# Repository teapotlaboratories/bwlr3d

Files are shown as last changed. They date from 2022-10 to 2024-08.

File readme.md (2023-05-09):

# Teapot BWLR3D
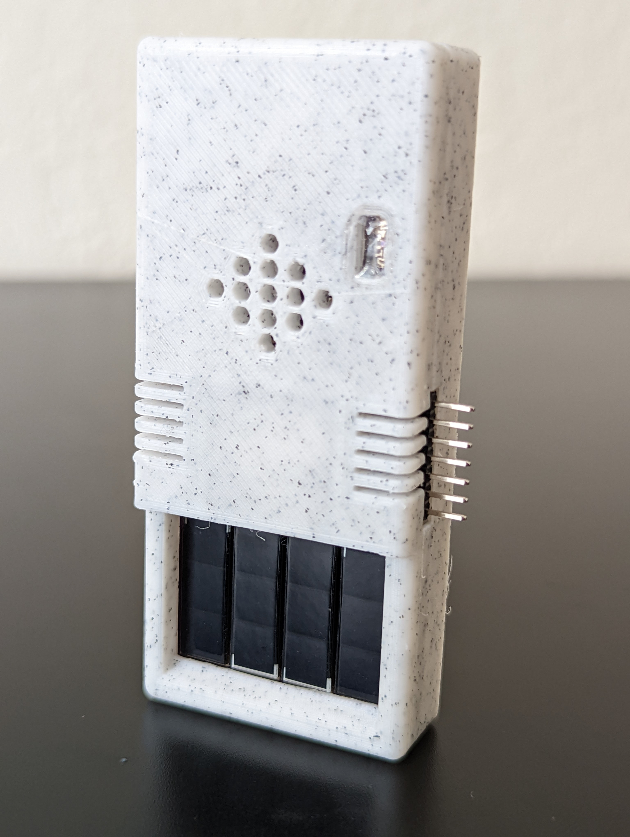
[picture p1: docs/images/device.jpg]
 
 
Teapot BWLR3D is an Asset Tracker and Environmental Sensor with Solar Energy Harvesting. 
The device is capable of sensing temperature, humidity, air pressure, air quality, light intensity using the on-board **BME688** plus **VEM7700**, and calculate device's AHRS using the **LSM6DSOX** as accelerometer and gyrometer with **LIS3MDL** as magnetometer. 
Equiped with low-power **L86-M33** GNSS module, the device is capable to locate itself anywhere in the world.
With **STM32WLE** MCU as it's core and **AEM10941** for solar charging, the device is capable ultra-low power operation with the possibility of indefinite battery-life by utilizing the solar charging capability.

Teapot BWLR3D is part of  [Teapot open-hardware project](https://github.com/teapotlaboratories). 
  
## Disclaimer
- The 1KM range is based on [AERQ - Air Quality Monitoring](https://github.com/Mircerson/AERQ/) design, but have not been tested on this device yet
- The position of the **BME688** sensor on the board might not be the most efficient
- The position of the **LIS3MDL** sensor might get interference from the surrounding components and the provided magnetic case does interfere with the sensor.

## Future Works
- Develop code to read sensor and send data when movement is detected. **LSM6DSOX** can be set to ultra-low power mode and set to wake MCU when movement is detected, all other sensors needs to be in power-down mode.
- Change `SW4` wiring from GND to 3V3, to allow booting to STM32WLE USART Bootloader. This enable the user to flash the RAK3172 module using STM32CubeProgrammer without ST-Link.

## Specification

- [RAK3172](https://docs.rakwireless.com/Product-Categories/WisDuo/RAK3172-Module/Overview/): An STM32WLE5CC module
- [AEM10941](https://e-peas.com/product/aem10941): Solar energy harvesting chip
- On-board sensors:
	- [L86-M33](https://www.quectel.com/product/gnss-l86): GNSS module
	- [LSM6DSOX](https://www.st.com/en/mems-and-sensors/lsm6dsox.html): Accelerometer and Gyrometer
	- [LIS3MDL](https://www.st.com/en/mems-and-sensors/lis3mdl.html): Magnetometer
	- [VEML7700](https://www.vishay.com/docs/84286/veml7700.pdf): Ambient Light Intensity meter
	- [BME688](https://www.bosch-sensortec.com/products/environmental-sensors/gas-sensors/bme688): Environmental sensor
- 3.3V only power/pin. 
- 12uA Deep-Sleep
- Switchable TX Power. 14 dBm(50mA) or 22 dBm(140mA) ( on 915MHz frequency )
- Supports LoRaWAN 1.0.3
- 1KM+ Range
- UART2 breakout for **Arduino** progamming
- SWD breakout for **Mbed OS/STM32Cube** programming
- IPEX antenna connector 
- 3.7 Volts LiPo Battery

## Schematics

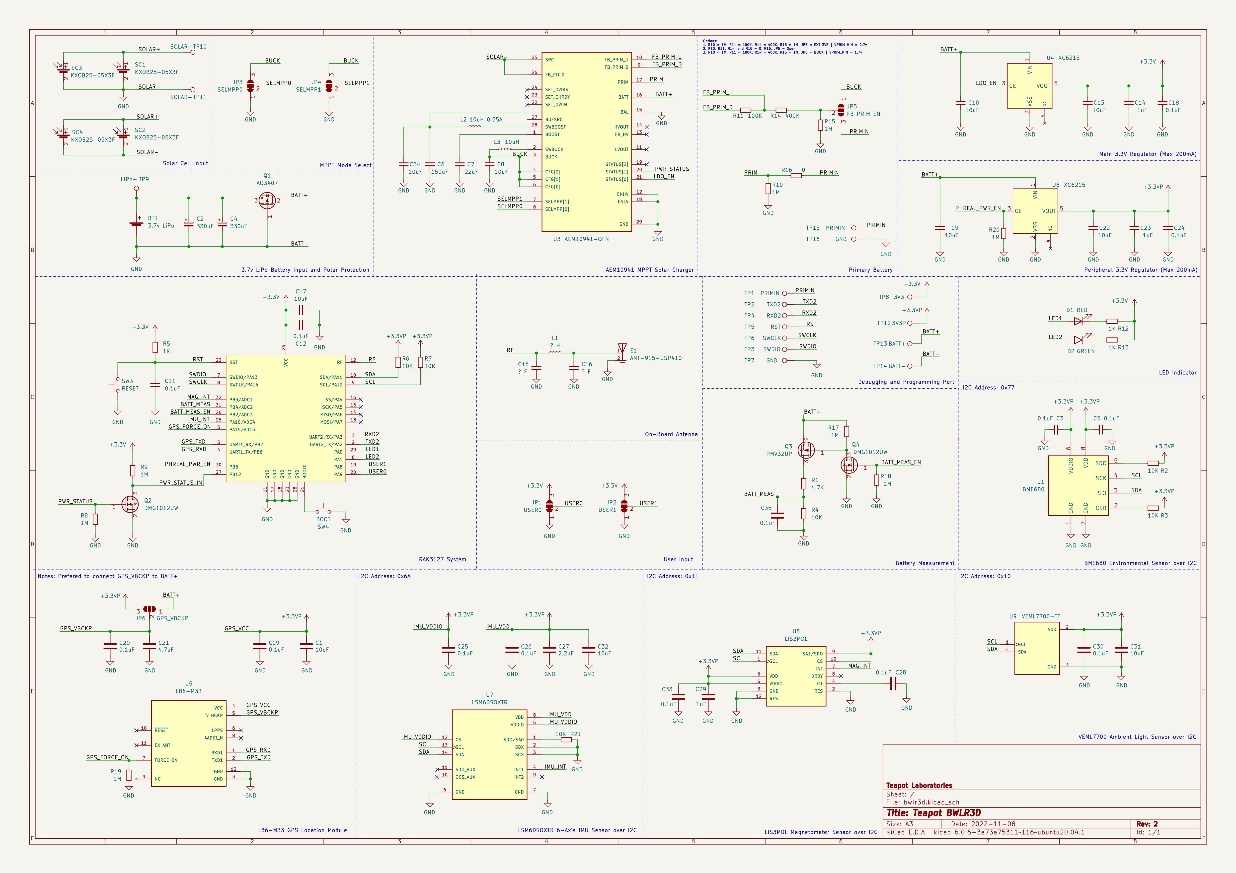
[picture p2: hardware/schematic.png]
schematic


Schematic revisions:
-   Revision 1: Initial design
-   Revision 2: Swap BATT_MEAS and IMU_INT pin, and add 0.1uF to voltage divider 

## Boards
 <p align="center">  pcb_render<br><b>PCB Render</b></p>

Built using KiCAD, the board is design to be as small as possible with all components placed on both side of the PCB.
The following design are based on the latest revision.
| Top Board | Bottom Board |
|--|--|
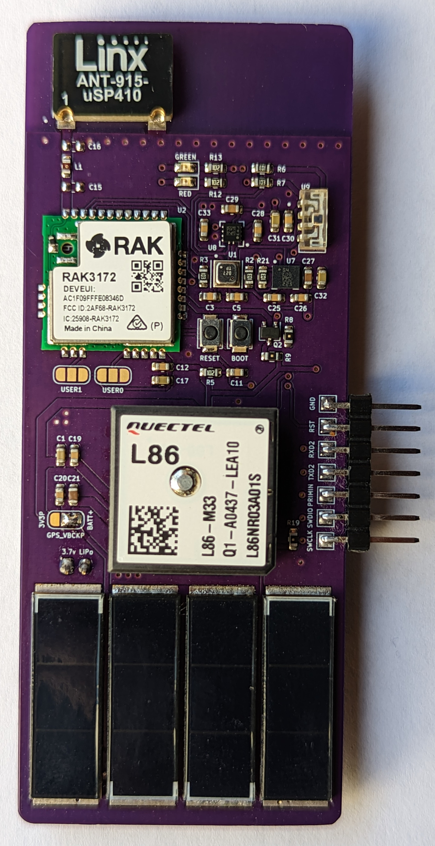
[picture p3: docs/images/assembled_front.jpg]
assembled_front
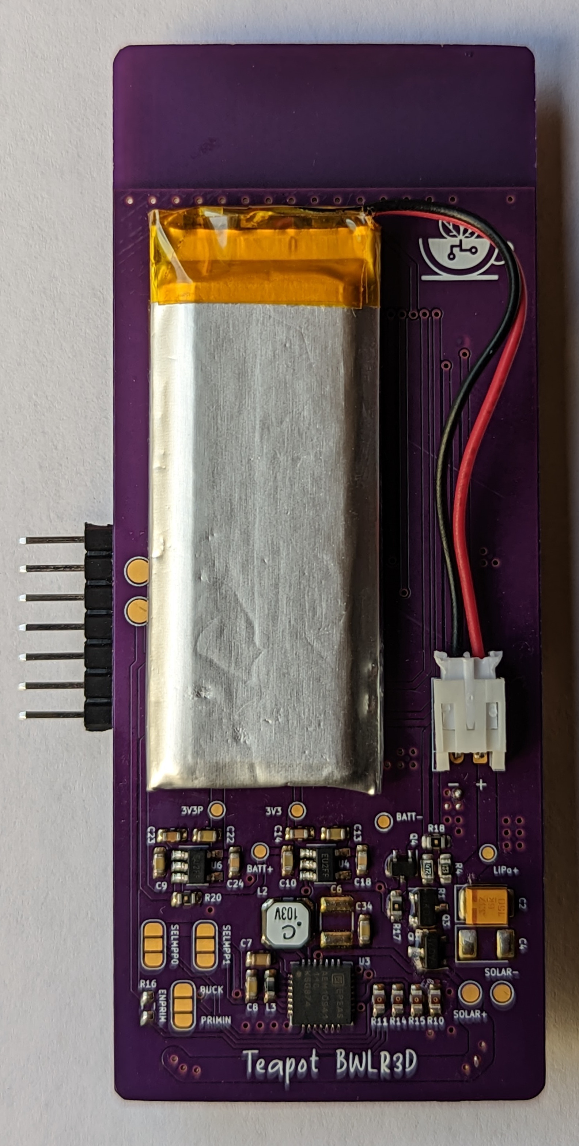
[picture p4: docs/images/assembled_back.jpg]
assembled_back
|  |  |
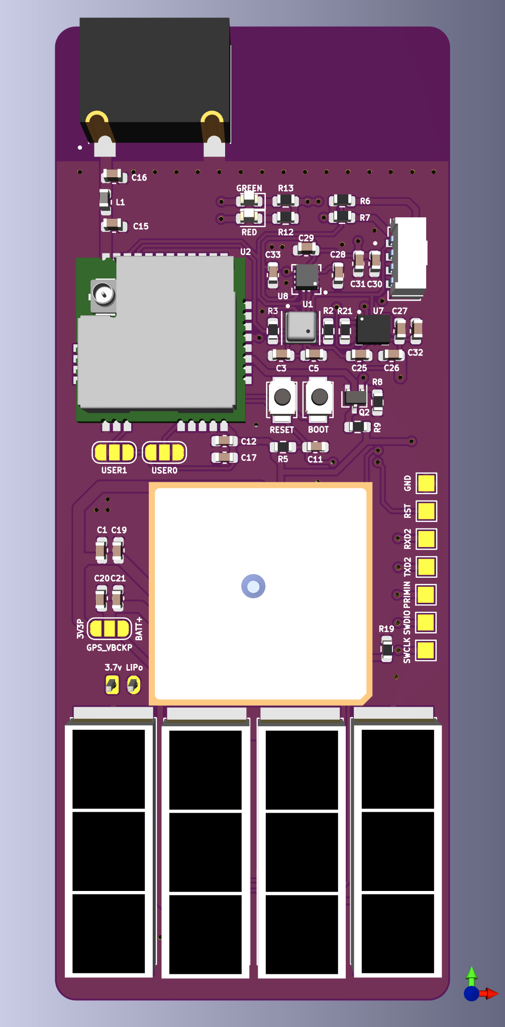
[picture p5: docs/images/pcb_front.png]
pcb_front
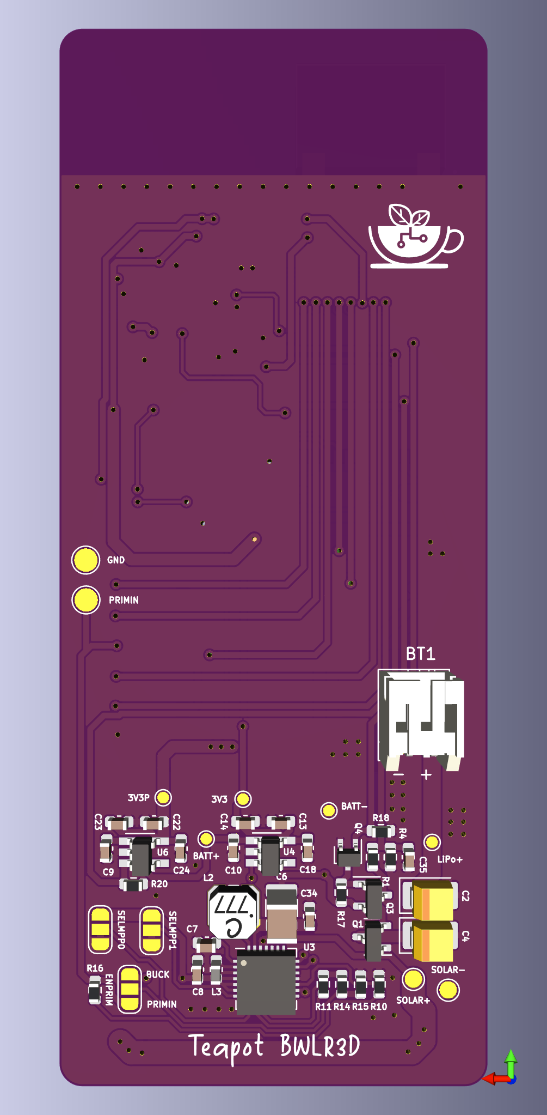
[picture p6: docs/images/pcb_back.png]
pcb_bottom
|  |  |

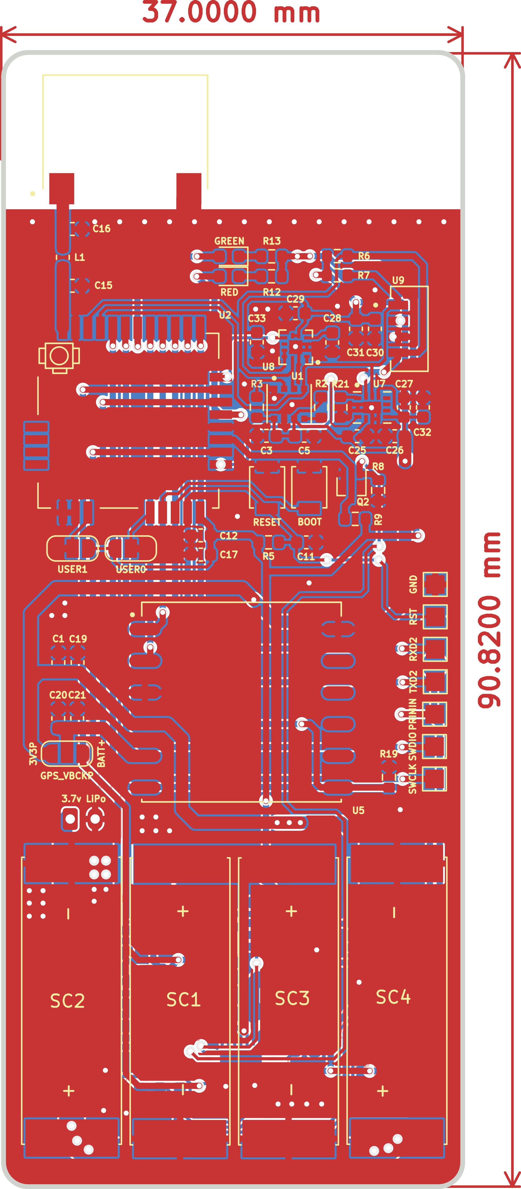
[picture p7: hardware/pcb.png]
pcb
 <p align="center"> <br><b>PCB Top and Bottom Layout</b></p> 
  
### Case
<p align="center">  case_render</p>

Built using [TinkerCAD](https://www.tinkercad.com), the cases are available with 2 variant, with or without the programming port. The cases are 3D printable with any generic 3D printer with/without suppport (depends on the orientation). The STL files are available [here](https://github.com/teapotlaboratories/bwlr3d/tree/main/hardware/case)
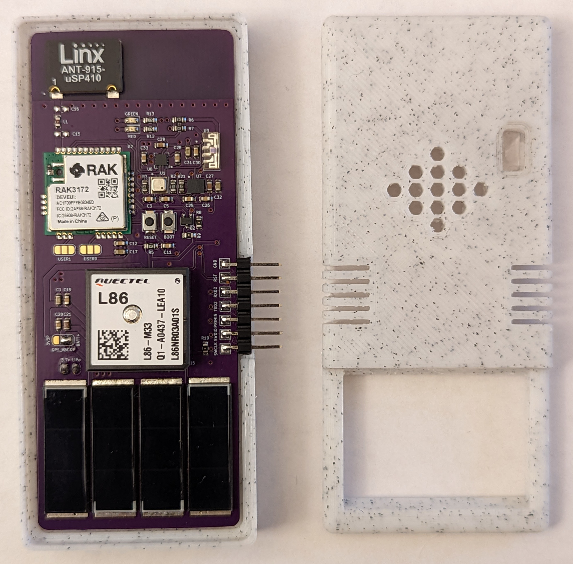
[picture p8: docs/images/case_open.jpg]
 <p align="center"><br><b>Case Open</b></p>

The case is design to be as small as possible with an additional magnets in the back to ease the placement of the sensor. The following are the list of material used at the time of testing:
- 3.7v LiPo Battery, 500 mAh 50mm x 22mm x 48mm
- 4 piece of 8mm x 2mm neodymium magnet

<p align="center">placement_showcase<br><b>Sensor Placement with Magnet</b></p>

### Measurement
Power consumption and solar charging current are measured using [Nordic PPK2](https://www.nordicsemi.com/Products/Development-hardware/Power-Profiler-Kit-2)  and [CurrentRanger](https://lowpowerlab.com/shop/product/152).
The following are the summary of the measurement:
- Transmit 102 bytes @ 14dBm:  225ms @ 48mA
- Deep-Sleep : 12 uA
- GNSS Fix - Cold Start: 15s @ 38mA
- GNSS Fix - Hot Start: 5s @ 35mA
- Sensor Read: 1.36s @ 9mA
- Direct Sunlight Solar Charge: 12mA
- Indirect Sunlight Solar Charge: 454uA

Notes: 
- GNSS time to fix depends on the conditions of the sky

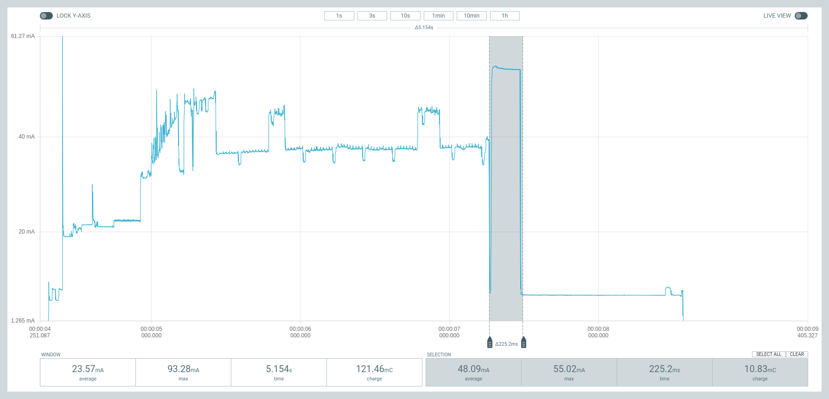
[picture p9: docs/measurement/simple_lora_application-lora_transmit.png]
lora_transmit
<p align="center"><br><b>LoRa Transmit</b></p>

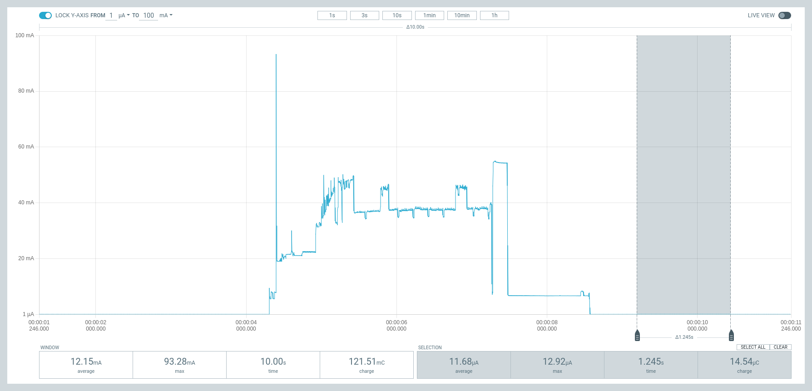
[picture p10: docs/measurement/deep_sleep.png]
deep_sleep
<p align="center"><br><b>Deep-Sleep</b></p>

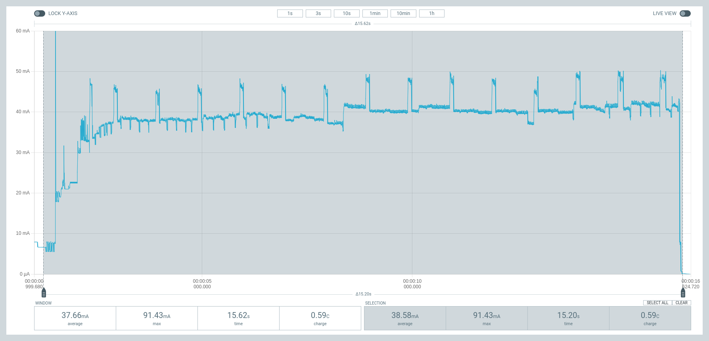
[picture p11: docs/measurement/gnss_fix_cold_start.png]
gnss_fix-cold_start
<p align="center"><br><b>GNSS Fix - Cold Start</b></p>

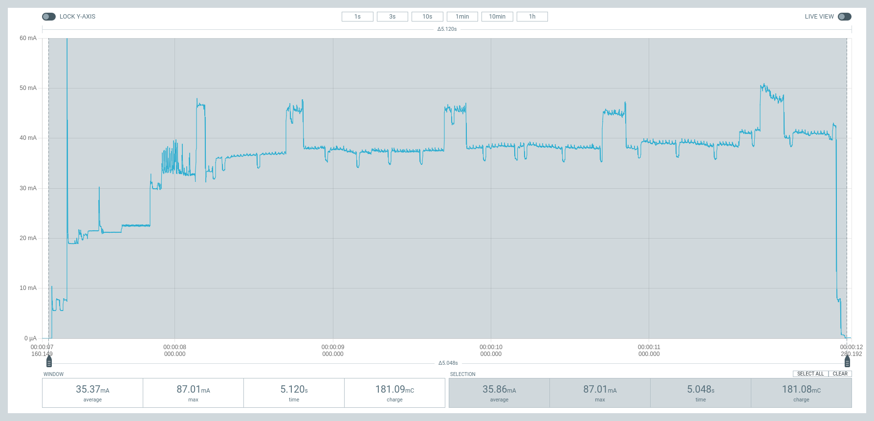
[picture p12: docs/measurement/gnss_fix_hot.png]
gnss_fix-hot_start
<p align="center"><br><b>GNSS Fix - Hot Start</b></p>

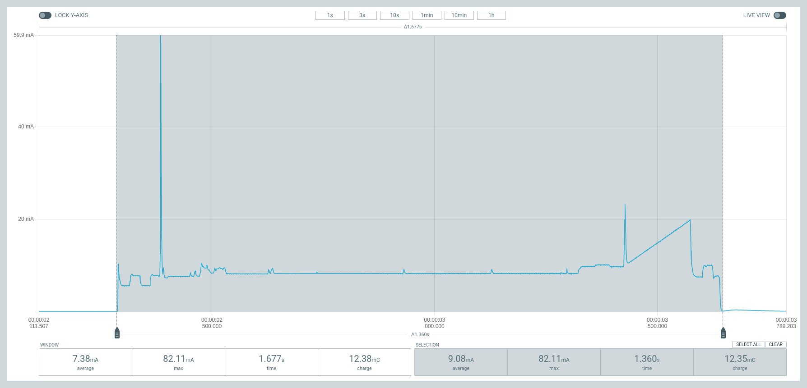
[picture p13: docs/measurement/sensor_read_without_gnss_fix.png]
sensor_read_without_gnss_fix
<p align="center"><br><b>Sensor Read</b></p>

| Solar Charge - Direct Sunlight | Solar Charge - Indirect Sunlight |
|--|--|
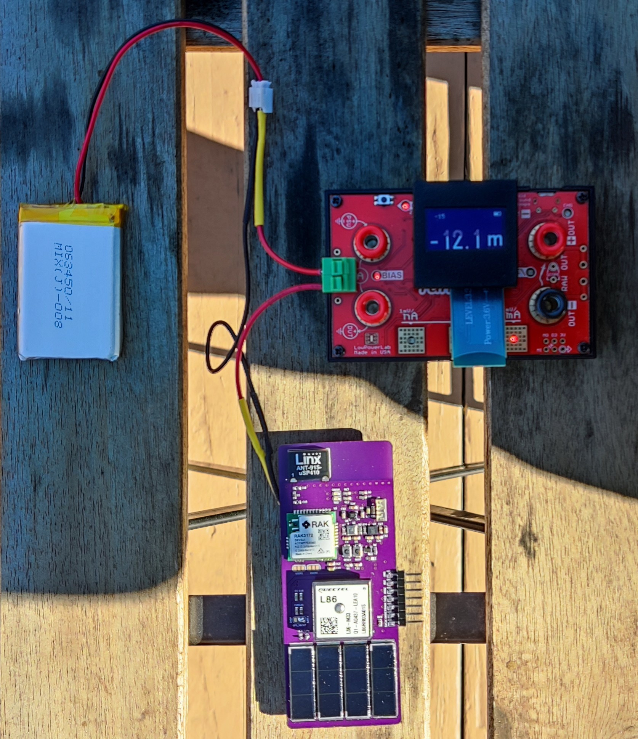
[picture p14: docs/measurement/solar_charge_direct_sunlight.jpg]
solar_charge_direct_sunlight
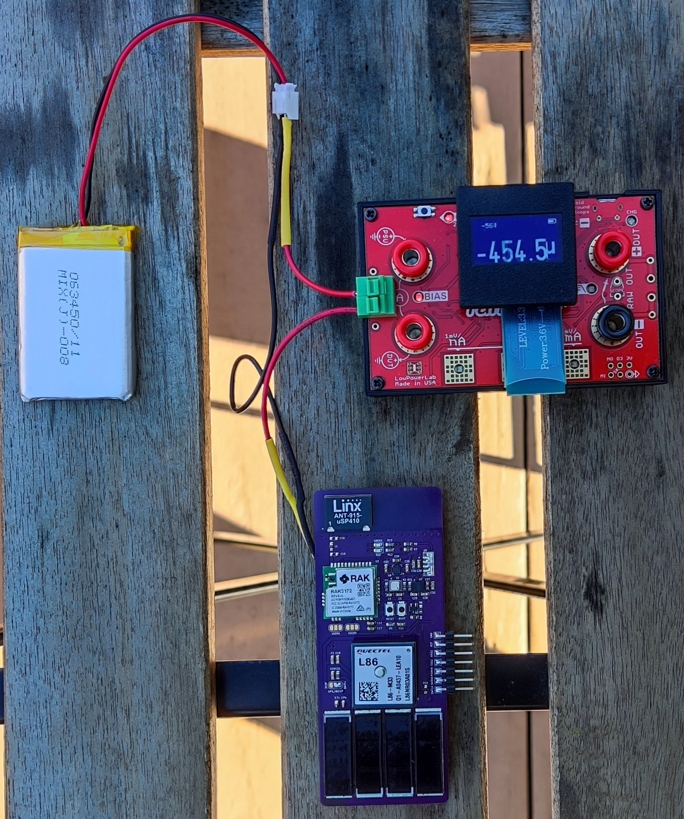
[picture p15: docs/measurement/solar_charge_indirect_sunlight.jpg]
solar_charge_indirect_sunlight
|  |  |

More measurement can be found [here](https://github.com/teapotlaboratories/bwlr3d/tree/main/docs/measurement)

### Bill Of Materials
Most of the components are generic and can be bought from any electornics/semi-conductor distributor. RAK3172 is the only component available in [RAKwireless store](https://store.rakwireless.com/products/wisduo-lpwan-module-rak3172?variant=40014759493830). The bill of materials can be downloaded [here](https://github.com/teapotlaboratories/bwlr3d/raw/main/hardware/bill_of_materials.csv)

> :warning: **Be sure to buy the RAK3172 variant without IPEX to use the On-Board Antenna** 

|Id |Designator |Package |Quantity|Designation |
|---|---|---|---|---|
|1  |BT1 |JST_PH_S2B-PH-K_1x02_P2.00mm_Horizontal|1 |3.7v |
|2  |C14,C23,C29 |C_0603_1608Metric |3 |1uF |
|3  |C17,C31,C32,C1,C9,C22,C8,C10,C34,C13 |C_0603_1608Metric |12 |10uF |
|4  |C2,C4 |CP_EIA-3528-15_AVX-H_Pad1.50x2.35mm |2 |330uF |
|5  |C21 |C_0603_1608Metric |1 |4.7uF |
|6  |C27 |C_0603_1608Metric |1 |2.2uF |
|7  |C5,C20,C26,C12,C28,C19,C30,C11,C25,C3,C33,C24,C18,C35|C_0603_1608Metric |14 |0.1uF |
|8  |C6 |C_1210_3225Metric |1 |150uF |
|9  |C7 |C_0603_1608Metric |1 |22uF |
|10 |D1 |LED_0603_1608Metric |1 |RED |
|11 |D2 |LED_0603_1608Metric |1 |GREEN |
|12 |E1 |ANT-915-USP410 |1 |ANT-915-USP410|
|13 |L2 |IND_LPS4012-103MRB |1 |10uH |
|14 |L3 |L_0603_1608Metric |1 |10uH |
|15 |Q1 |SOT-23 |1 |PJA3407 |
|16 |Q2,Q4 |SOT-323_SC-70 |2 |DMG1012UW |
|17 |Q3 |SOT-23 |1 |PMV27UPER |
|18 |R1 |R_0603_1608Metric |1 |4.7K |
|19 |R11 |R_0603_1608Metric |1 |100K |
|20 |R12,R13,R5 |R_0603_1608Metric |3 |1K |
|21 |R14 |R_0603_1608Metric |1 |400K |
|22 |R16 |R_0603_1608Metric |6 |0 |
|23 |R7,R2,R3,R6,R21,R4 |R_0603_1608Metric |6 |10K |
|24 |R9,R8,R19,R15,R18,R10,R17,R20 |R_0603_1608Metric |8 |1M |
|25 |SC4,SC1,SC3,SC2 |KXOB25-05X3F |4 |KXOB25-05X3F  |
|26 |SW3 |SW_SPST_B3U-1000P |1 |RESET |
|27 |SW4 |SW_SPST_B3U-1000P |1 |BOOT |
|28 |U1 |BME688 |1 |BME688 |
|29 |U2 |RAK3172 |1 |RAK3172 |
|30 |U3 |QFN-28-1EP_5x5mm_P0.5mm_EP3.35x3.35mm  |1 |AEM10941-QFN  |
|31 |U5 |L86-M33 |1 |L86-M33 |
|32 |U6,U4 |SOT-23-5 |2 |XC6215 |
|33 |U7 |PQFN50P250X300X97-14N_0.59x0.30 |1 |LSM6DSOXTR |
|34 |U8 |LGA12_ST |1 |LIS3MDL |
|35 |U9 |VEML7700-TT |1 |VEML7700-TT |

## Programming

> :warning: **Board can only be powered using the LiPo Battery** 

Programming the device can be done over the **UART2** or **SWD**, available on the right side of the board.
Out of the factory, the RAK3172 chip ships with an **AT firmware** that can be tested by connecting a USB-to-UART bridge to the **UART2** port.

The following are some very good tutorial to start developing with the device:

 - [Communicating with the AT firmware](https://docs.rakwireless.com/Product-Categories/WisDuo/RAK3172-Module/Quickstart/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)
 - [Programming with Arduino](https://docs.rakwireless.com/Product-Categories/WisDuo/RAK3172-Module/Quickstart/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)
 - [Programming with STM32Cube](https://docs.rakwireless.com/Product-Categories/WisDuo/RAK3172-Module/Low-Level-Development/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)
 - [Programming with MbedOS](https://github.com/hallard/LoRa-E5-Tiny/blob/main/README.md#compile-and-flash-firmware)

For connecting to the **UART2** port, use any USB-to-UART bridge module. In testing, the [Sparkfun](https://www.sparkfun.com/products/14050) board is used for communication with AT firmware and programming over **Arduino**.
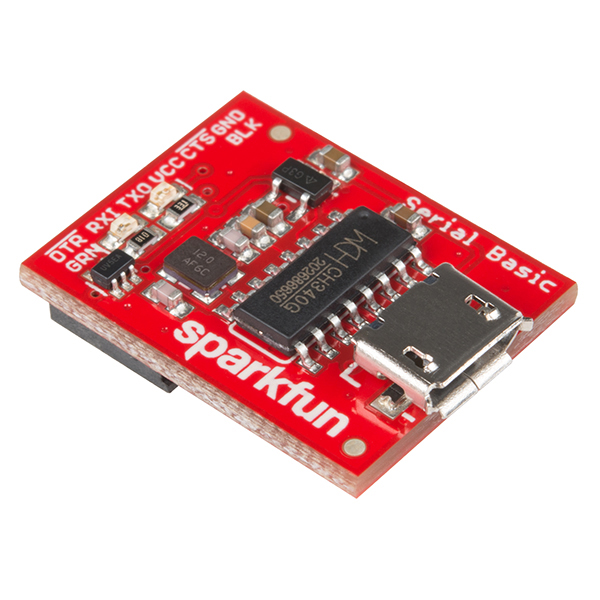
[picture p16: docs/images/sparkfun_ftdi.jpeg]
 <p align="center"> <br>Sparkfun USB-to-UART Bridge</p>

> :warning: **Be sure to only use 3.3V module. Do not 5V module** 

For connecting to the **SWD** port, use ST-Link v2  in-circuit debugger and programmer from STM. In testing, ST-Link v2 clone will not work. The ST-Link v2 should atleast be reconizeable by the [STM32CubeProgrammer](https://www.st.com/en/development-tools/stm32cubeprog.html).
A cheap and alternative way to get an authorized ST-Link is to buy a Nucleo board, cut the top part which contain the ST-Link and use it as an external programmer.
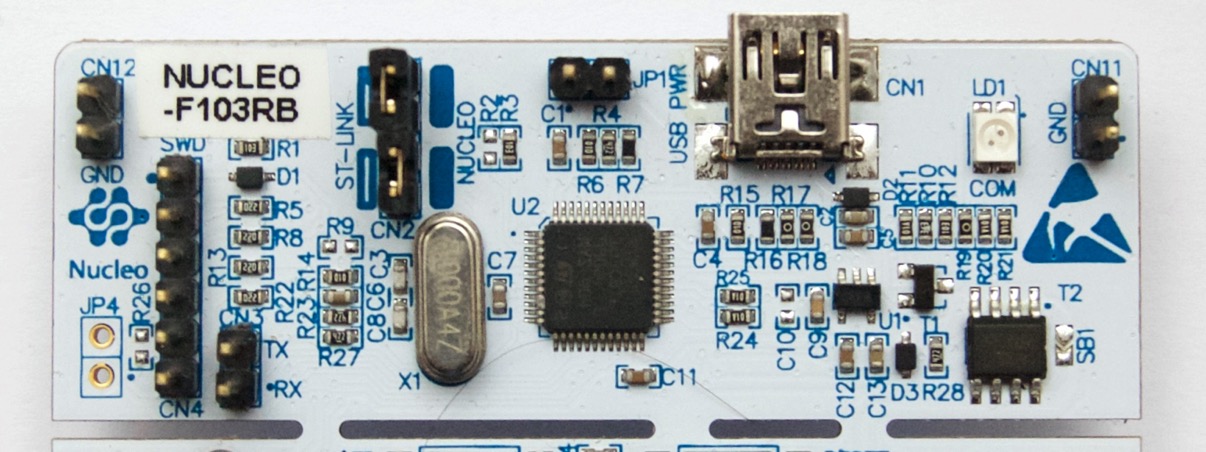
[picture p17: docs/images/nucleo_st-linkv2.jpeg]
 <p align="center"> <br>ST-Link v2 from a Nucleo Development Board</p>
Here are some good tutorial to convert a Nucleo to and external ST-Link v2:

 - https://www.radioshuttle.de/en/turtle-en/nucleo-st-link-interface-en/
 - https://jeelabs.org/book/1547a/index.html

## Notes
There are some issue, notes, and behavior that was discovered at the time of testing and development. The following are those discovery:
- Soldering the solar cell is better to be done manually using a soldering iron. Without proper reflow oven, it may damage the solar cell and reduces it's efficiency
- PRIMIN is available to use as the input for AEM10941 Primary Battery input. See schematic for more detail	

## Reference
The project won't be possible without the amazing work from people across the globe. The following are the reference to those awesome projects:

 - [LoRa e5 Tiny](https://github.com/hallard/LoRa-E5-Tiny)
 - [AERQ - Air Quality Monitoring](https://github.com/Mircerson/AERQ/)
 - [TSEM](https://hackaday.io/project/159139-tiny-solar-energy-module-tsem)

## License
The product is open-source! However, some part of library used under **src**, might have it's own license.
Please reach out or create a ticket to report any license violation.



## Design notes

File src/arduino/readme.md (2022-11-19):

# Source Code
 Here are the examples code for the Teapot BWLR3D device. The provided code here are not intended for production and only use to understand on how to interact with the components on the device.
- **I2CScan**: Test the communication to all I2C sensors.
	- Power-on all on-board sensor and ping all available I2C address
- **BoardTest**: Test LED indicator and read battery voltage.
- **DeepSleep**: Test deep-sleep capability of the device
- **GNSSSleep**: Test setting the L86-M33 module to sleep
- **PowerTest**: Test and measure power consumption for multiple case
- **SensorTest**: Test reading all on-board sensor
- **SimpleLoRaApplication**: Simple LoRa application with simple and inefficient payload encoding. 
	- Connect to a LoRaWAN Gateway at boot
	- Get GNSS first fix ( loop indefintely until get satellite fix )
	- Periodically send sensor data to gateway
	- Periodically send gnss data to gateway
	- Interval for read plus transmit sensor data and gnss data can be different

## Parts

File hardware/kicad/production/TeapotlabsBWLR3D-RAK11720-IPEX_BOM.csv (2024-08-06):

Id | Designator | Quantity | Manufacturer | Manufacturer Part Number | Value | Description | Footprint | Type | Distributor | Distributor Part Number | Distributor Link
1 | BT1 | 1 | JST | S2B-PH-K-S(LF)(SN) | 3.7v | 1x2P 2P PH Tin 2 -25?~+85? 2A 1 2mm Brass Bend insert Push-Pull,P=2mm Wire To Board Connector ROHS | JST_PH_S2B-PH-K_1x02_P2.00mm_Horizontal | THT | LCSC | C173752 | https://www.lcsc.com/product-detail/Wire%20To%20Board%20Connector_JST-S2B-PH-K-S-LF-SN_C173752.html
2 | C14,C23,C29 | 3 | Samsung Electro-Mechanics | CL10B105KP8NNNC | 1u | 10V 1uF X7R ±10% 0603 Multilayer Ceramic Capacitors MLCC - SMD/SMT ROHS | 0603_1608Metric | SMD | LCSC | C95843 | https://www.lcsc.com/product-detail/Multilayer-Ceramic-Capacitors-MLCC-SMD-SMT_Samsung-Electro-Mechanics-CL10B105KP8NNNC_C95843.html
3 | C17,C31,C32,C1,C9,C22,C8,C10,C34,C13 | 12 | Murata Electronics | GRM188Z71A106KA73D | 10u | 10V 10uF X7R ±10% 0603 Multilayer Ceramic Capacitors MLCC - SMD/SMT ROHS | 0603_1608Metric | SMD | LCSC | C2959727 | https://www.lcsc.com/product-detail/Multilayer-Ceramic-Capacitors-MLCC-SMD-SMT_Murata-Electronics-GRM188Z71A106KA73D_C2959727.html
4 | C21 | 1 | Murata Electronics | GRM188Z71A475KE15D | 4u7 | 10V 4.7uF X7R ±10% 0603 Multilayer Ceramic Capacitors MLCC - SMD/SMT ROHS | 0603_1608Metric | SMD | LCSC | C913474 | https://www.lcsc.com/product-detail/Multilayer-Ceramic-Capacitors-MLCC-SMD-SMT_Murata-Electronics-GRM188Z71A475KE15D_C913474.html
5 | C27 | 1 | Samsung Electro-Mechanics | CL10B225KP8NNNC | 2u2 | 10V 2.2uF X7R ±10% 0603 Multilayer Ceramic Capacitors MLCC - SMD/SMT ROHS | 0603_1608Metric | SMD | LCSC | C100082 | https://www.lcsc.com/product-detail/Multilayer-Ceramic-Capacitors-MLCC-SMD-SMT_Samsung-Electro-Mechanics-CL10B225KP8NNNC_C100082.html
6 | C5,C20,C26,C12,C28,C19,C30,C11,C25,C3,C33,C24,C18,C35 | 14 | YAGEO | CC0603KRX7R6BB104 | 100n | 10V 100nF X7R ±10% 0603 Multilayer Ceramic Capacitors MLCC - SMD/SMT ROHS | 0603_1608Metric | SMD | LCSC | C519438 | https://www.lcsc.com/product-detail/Multilayer-Ceramic-Capacitors-MLCC-SMD-SMT_YAGEO-CC0603KRX7R6BB104_C519438.html
7 | C7 | 1 | Murata Electronics | GRM188R61A226ME15D | 22u | 10V 22uF X5R ±20% 0603 Multilayer Ceramic Capacitors MLCC - SMD/SMT ROHS | 0603_1608Metric | SMD | LCSC | C84419 | https://www.lcsc.com/product-detail/Multilayer-Ceramic-Capacitors-MLCC-SMD-SMT_Murata-Electronics-GRM188R61A226ME15D_C84419.html
8 | D1 | 1 | Lite-On | LTST-C191KRKT | RED | Red 2V 20mA | LED_0603_1608Metric | SMD | LCSC | C125099 | https://www.lcsc.com/product-detail/Light-Emitting-Diodes-LED_Lite-On-LTST-C191KRKT_C125099.html
9 | D2 | 1 | Lite-On | LTST-C190KGKT | GREEN | Green 2V 20mA | LED_0603_1608Metric | SMD | LCSC | C125094 | https://www.lcsc.com/product-detail/Light-Emitting-Diodes-LED_Lite-On-LTST-C190KGKT_C125094.html
10 | L2 | 1 | Coilcraft | LPS4012-103MRC | 10u | Power Inductor 10uH 20% 1.1A | IND_LPS4012-103MRB | SMD | Mouser | 994-LPS4012-103MRC | https://www.mouser.com/ProductDetail/994-LPS4012-103MRC
11 | L3 | 1 | TDK | MLZ1608M100WT000 | 10u | 10uH ±20% 90mA 1.05? 0603 Inductors (SMD) ROHS | 0603_1608Metric | SMD | LCSC | C76798 | https://www.lcsc.com/product-detail/Inductors-SMD_TDK-MLZ1608M100WT000_C76798.html
12 | Q1 | 1 | Alpha & Omega Semicon | AO3407A | AO3407A | P-Channel Enhacnement Mode MOSFET 30V 4.3A 48mÎ©@10V | SOT-23 | SMD | LCSC | C15155 | https://www.lcsc.com/product-detail/MOSFETs_Alpha-Omega-Semicon-AO3407A_C15155.html
13 | Q2,Q4 | 2 | TECH PUBLIC | DMG1012UW | DMG1012UW | N-Channel Enhancement Mode MOSFET 20V 0.9A 300mÎ©@2.5V | SOT-323_SC-70 | SMD | LCSC | C2940609 | https://www.lcsc.com/product-detail/MOSFETs_TECH-PUBLIC-DMG1012UW_C2940609.html
14 | Q3 | 1 | Nexperia | PMV27UPEAR | PMV27UPER | 20V 4.5A 32m?@4.5A,4.5V 950mV@250uA 1 Piece P-Channel SOT-23 MOSFETs ROHS | SOT-23 | SMD | LCSC | C553088 | https://www.lcsc.com/product-detail/MOSFETs_Nexperia-PMV27UPEAR_C553088.html
15 | R1 | 1 | UNI-ROYAL(Uniroyal Elec) | 0603WAF4701T5E | 4K7 | 100mW Thick Film Resistors 75V ±100ppm/? ±1% 4.7k? 0603 Chip Resistor - Surface Mount ROHS | 0603_1608Metric | SMD | LCSC | C23162 | https://www.lcsc.com/product-detail/Chip-Resistor-Surface-Mount_UNI-ROYAL-Uniroyal-Elec-0603WAF4701T5E_C23162.html
16 | R11,R14 | 2 | UNI-ROYAL(Uniroyal Elec) | 0603WAF0000T5E | 0 | 100mW Thick Film Resistors 75V ±1% 0? 0603 Chip Resistor - Surface Mount ROHS | 0603_1608Metric | SMD | LCSC | C21189 | https://www.lcsc.com/product-detail/Chip-Resistor-Surface-Mount_UNI-ROYAL-Uniroyal-Elec-0603WAF0000T5E_C21189.html
17 | R12,R13,R5 | 3 | FOJAN | FRC0603J102TS | 1K | 100mW Thick Film Resistors 75V ±100ppm/? ±5% 1k? 0603 Chip Resistor - Surface Mount ROHS | 0603_1608Metric | SMD | LCSC | C2907113 | https://www.lcsc.com/product-detail/_FOJAN-_C2907113.html
18 | R7,R2,R3,R6,R21,R4 | 6 | YAGEO | RC0603JR-0710KL | 10K | 100mW Thick Film Resistors 75V ±100ppm/? ±5% 10k? 0603 Chip Resistor - Surface Mount ROHS | 0603_1608Metric | SMD | LCSC | C99198 | https://www.lcsc.com/product-detail/_YAGEO-_C99198.html
19 | R9,R8,R19,R15,R18,R10,R17,R20 | 8 | UNI-ROYAL(Uniroyal Elec) | 0603WAJ0105T5E | 1M | 100mW Thick Film Resistors 75V ±100ppm/? ±5% 1M? 0603 Chip Resistor - Surface Mount ROHS | 0603_1608Metric | SMD | LCSC | C26098 | https://www.lcsc.com/product-detail/Chip-span-style-background-color-ff0-Resistor-span-Surface-Mount_UNI-ROYAL-Uniroyal-Elec-0603WAJ0105T5E_C26098.html
20 | SC4,SC1,SC3,SC2 | 4 | ANYSOLAR Ltd | KXOB25-05X3F | KXOB25-05X3F | Monocrystalline Solar Cell 30.7 mW 2.07 V | KXOB25-05X3F | SMD | Digikey | KXOB25-05X3FCT-ND | https://www.digikey.com/en/products/detail/anysolar-ltd/KXOB25-05X3F-TR/9990478
22 | SW3 | 1 | Omron Electronics | B3U-1000P | RESET | 2.5mm 1.6mm Round Button 50mA Standing paste 3mm SPST 153gf 12V SMD,2.5x3mm Tactile Switches ROHS | SW_SPST_B3U-1000P | SMD | LCSC | C231329 | https://www.lcsc.com/product-detail/Tactile-Switches_Omron-Electronics-B3U-1000P_C231329.html
23 | SW4 | 1 | Omron Electronics | B3U-1000P | BOOT | 2.5mm 1.6mm Round Button 50mA Standing paste 3mm SPST 153gf 12V SMD,2.5x3mm Tactile Switches ROHS | SW_SPST_B3U-1000P | SMD | LCSC | C231329 | https://www.lcsc.com/product-detail/Tactile-Switches_Omron-Electronics-B3U-1000P_C231329.html
24 | U1 | 1 | Bosch Sensortec | BME688 | BME688 | SMD-8P Temperature and Humidity Sensor ROHS | BME688 | SMD | LCSC | C3664478 | https://www.lcsc.com/product-detail/Temperature-and-Humidity-Sensor_Bosch-Sensortec-BME688_C3664478.html
25 | U2 | 1 | RAKwireless | 305051 | RAK11720 | RAK11720 Module with IPEX, Frequency 8xx MHz, Band EU868 | RAK11720 | SMD | RAKwireless | 305051 | Contact inquiry@rakwireless.com for SKU: 305051
26 | U3 | 1 | e-peas | AEM10941-QFN | AEM10941 | Photovoltaic Energy Harvesting Manager | QFN-28-1EP_5x5mm_P0.5mm_EP3.35x3.35mm | SMD | Mouser | 120-AEM10941-QFN | https://www.mouser.com/ProductDetail/e-peas/AEM10941-QFN?qs=W%2FMpXkg%252BdQ7CeqB2lBPbRQ%3D%3D
27 | U5 | 1 | Quectel | L86-M33 | L86-M33 | Navigation Galileo, GLONASS, GPS, GNSS Transceiver Module 1.575GHz, 1.601GHz Integrated, Ceramic Patch Surface Mount | L86-M33 | SMD | Digikey | 2958-L86-M33CT-ND | https://www.digikey.com/en/products/detail/quectel/L86-M33/13278361
28 | U6,U4 | 2 | Torex Semicon | XC6215B332MR-G | XC6215 | 300mA Fixed 3.3V Positive electrode 7V SOT-23-5 Voltage Regulators - Linear, Low Drop Out (LDO) Regulators ROHS | SOT-23-5 | SMD | LCSC | C98230 | https://www.lcsc.com/product-detail/Voltage-Regulators-Linear-Low-Drop-Out-LDO-Regulators_Torex-Semicon-XC6215B332MR-G_C98230.html
29 | U7 | 1 | STMicroelectronics | LSM6DSOXTR | LSM6DSOXTR | IMUs - Inertial Measurement Units iNEMO inertial module Machine Learning Core, Finite State Machine & advanced Dig | LGA-14(2.5x3) | SMD | Mouser | 511-LSM6DSOXTR | https://www.mouser.com/ProductDetail/511-LSM6DSOXTR
30 | U8 | 1 | STMicroelectronics | LIS3MDLTR | LIS3MDL | Board Mount Hall Effect / Magnetic Sensors Ultra Lo-Pwr Hi Perf 3-Axis 1.9-3.6V | LGA12_ST | SMD | Mouser | 511-LIS3MDLTR | https://www.mouser.com/ProductDetail/511-LIS3MDLTR
31 | U9 | 1 | STMicroelectronics | VEML7700-TT | VEML7700-TT | Ambient Light Sensors Opr 2.5-3.6V 0.005lx Top View 16bit I2C | VEML7700-TT | SMD | Mouser | 78-VEML7700-TT | https://www.mouser.com/ProductDetail/78-VEML7700-TT
32 | L1 | 1 | - | - | DNP | Do Not Populate | - | DNP | - | - | -
33 | C15,C16 | 2 | - | - | DNP | Do Not Populate | - | DNP | - | - | -
34 | C2,C4 | 2 | - | - | DNP | Do Not Populate | - | DNP | - | - | -
35 | C6 | 1 | - | - | DNP | Do Not Populate | - | DNP | - | - | -
36 | E1 | 1 | - | - | DNP | Do Not Populate | - | DNP | - | - | -
37 | R16 | 1 | - | - | DNP | Do Not Populate | - | DNP | - | - | -

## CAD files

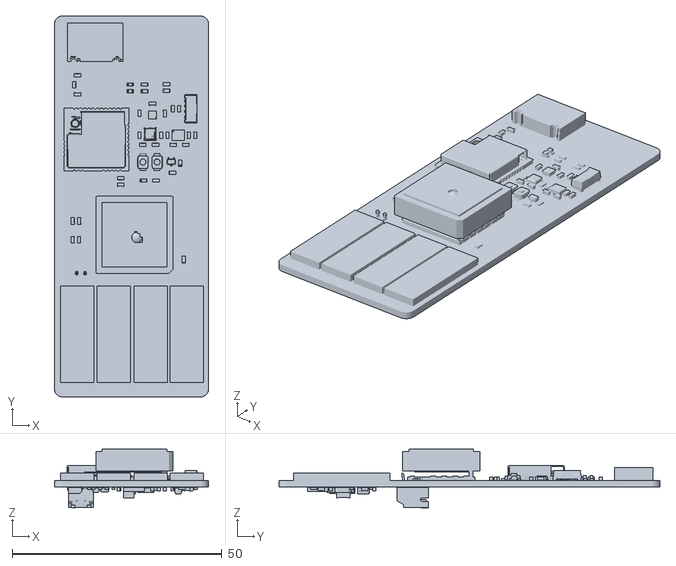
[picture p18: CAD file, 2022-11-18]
docs/assembeld_board.stl
36.8 x 90.9 x 14.0

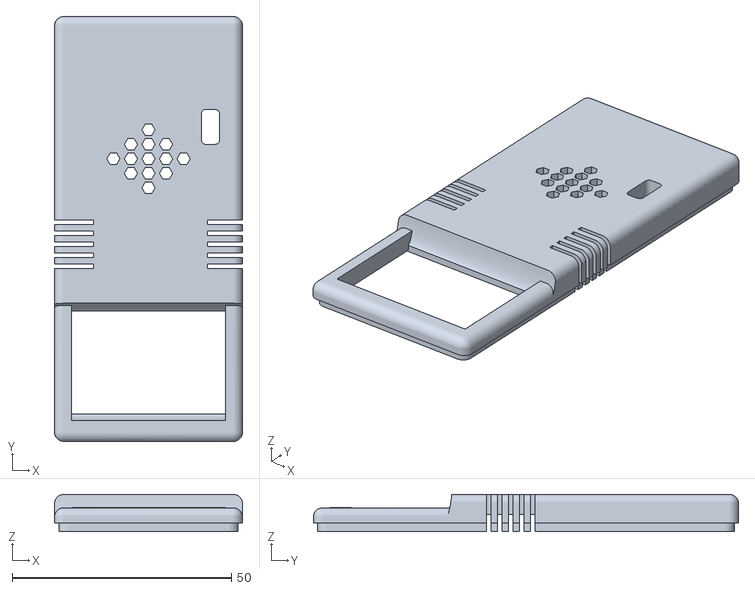
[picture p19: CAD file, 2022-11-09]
hardware/case/top.stl
42.8 x 96.9 x 8.46

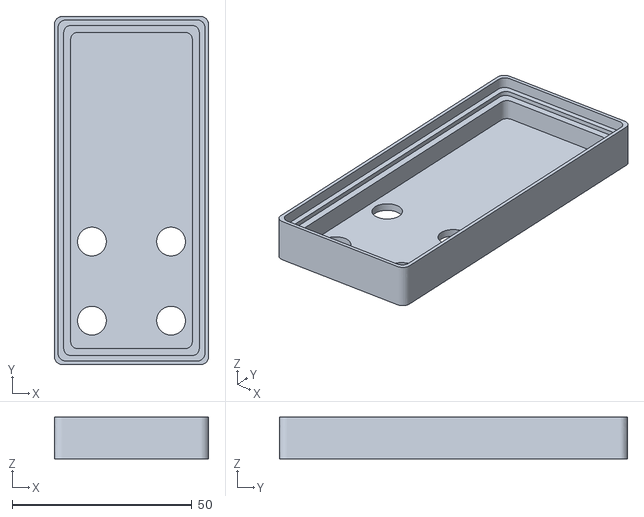
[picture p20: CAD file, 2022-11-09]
hardware/case/bottom.stl
42.8 x 96.9 x 11.6

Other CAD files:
hardware/case/top_with_programming_port.stl
hardware/case/bottom_with_programming_port.stl

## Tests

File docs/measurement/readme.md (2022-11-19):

# Measurement
Power consumption and solar charging current are measured using [Nordic PPK2](https://www.nordicsemi.com/Products/Development-hardware/Power-Profiler-Kit-2)  and [CurrentRanger](https://lowpowerlab.com/shop/product/152).
The following are the summary of the measurement:
- Transmit 102 bytes @ 14dBm:  225ms @ 48mA
- Deep-Sleep : 12 uA
- GNSS Fix - Cold Start: 15s @ 38mA
- GNSS Fix - Hot Start: 5s @ 35mA
- Sensor Read: 1.36s @ 9mA
- Direct Sunlight Solar Charge: 12mA
- Indirect Sunlight Solar Charge: 454uA

Notes: 
- GNSS time to fix depends on the conditions of the sky

## LoRa Transmit
<p align="center">lora_transmit</p>

## Deep-Sleep
<p align="center">deep_sleep</p>

## GNSS Fix - Cold Start
<p align="center">gnss_fix-cold_start</p>

## GNSS Fix - Hot Start
<p align="center">gnss_fix-hot_start</p>

## Sensor Read without GNSS Fix
<p align="center">sensor_read_without_gnss_fix</p>

## Sensor Read with GNSS Fix
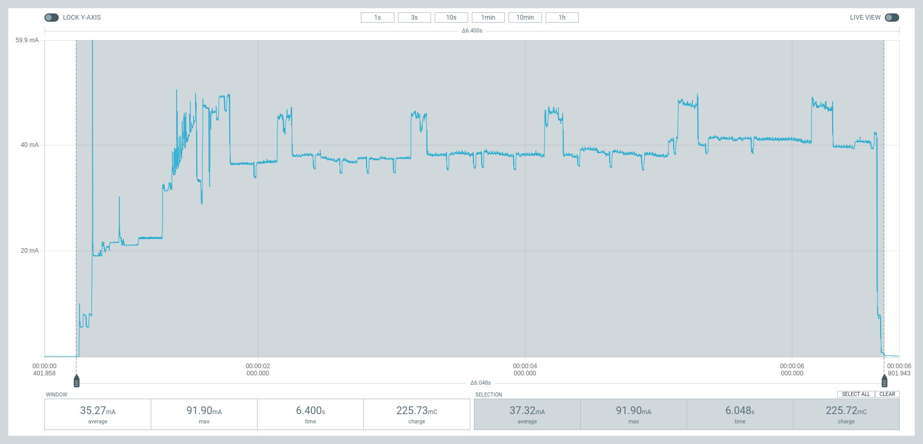
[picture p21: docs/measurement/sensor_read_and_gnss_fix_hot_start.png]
sensor_read_and_gnss_fix_hot_start


## Simple LoRa Application - Sensor Read and GNSS Fix then Transmit
Power consumption for the **SimpleLoraApplication** when it read all sensor data, wait for GNSS fix and LoRa transmit
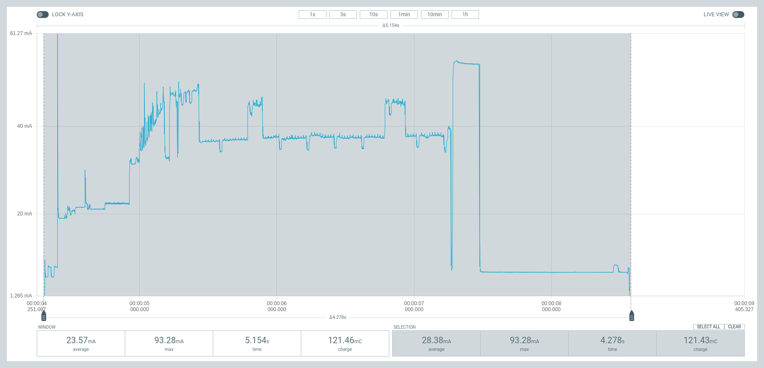
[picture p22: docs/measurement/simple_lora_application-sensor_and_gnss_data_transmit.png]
simple_lora_application-sensor_and_gnss_data_transmit


## Simple LoRa Application - Sensor Read Fix then Transmit
Power consumption for the **SimpleLoraApplication** when it read all sensor data and LoRa transmit
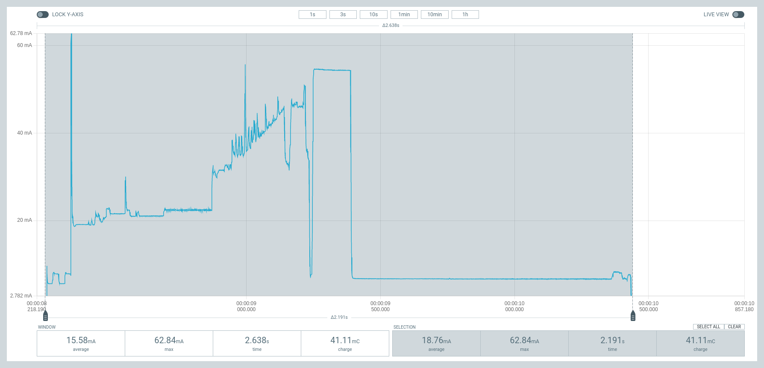
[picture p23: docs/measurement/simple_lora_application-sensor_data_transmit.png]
simple_lora_application-sensor_data_transmit


## Solar Charge - Direct Sunlight
<p align="center">solar_charge_direct_sunlight</p>

## Solar Charge - Indirect Sunlight
<p align="center">solar_charge_indirect_sunlight</p>

## Solar Charge - Indirect Low Sunlight
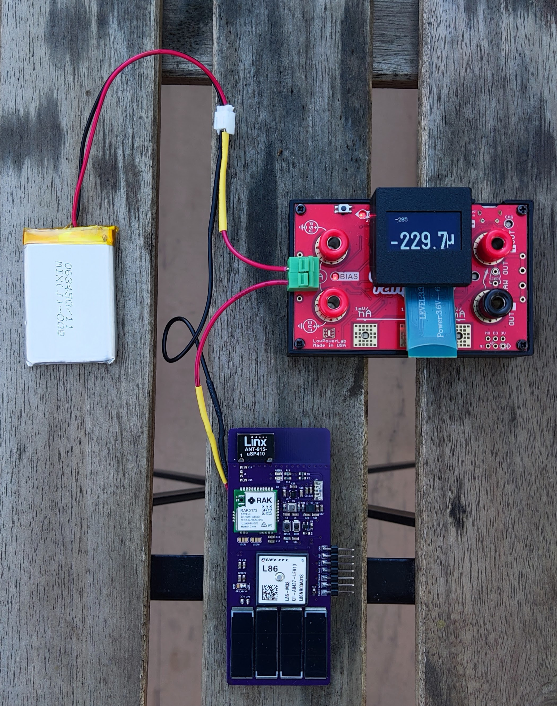
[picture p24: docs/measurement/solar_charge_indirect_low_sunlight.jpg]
solar_charge_indirect_low_sunlight


## Solar Charge - Indirect Very Low Sunlight
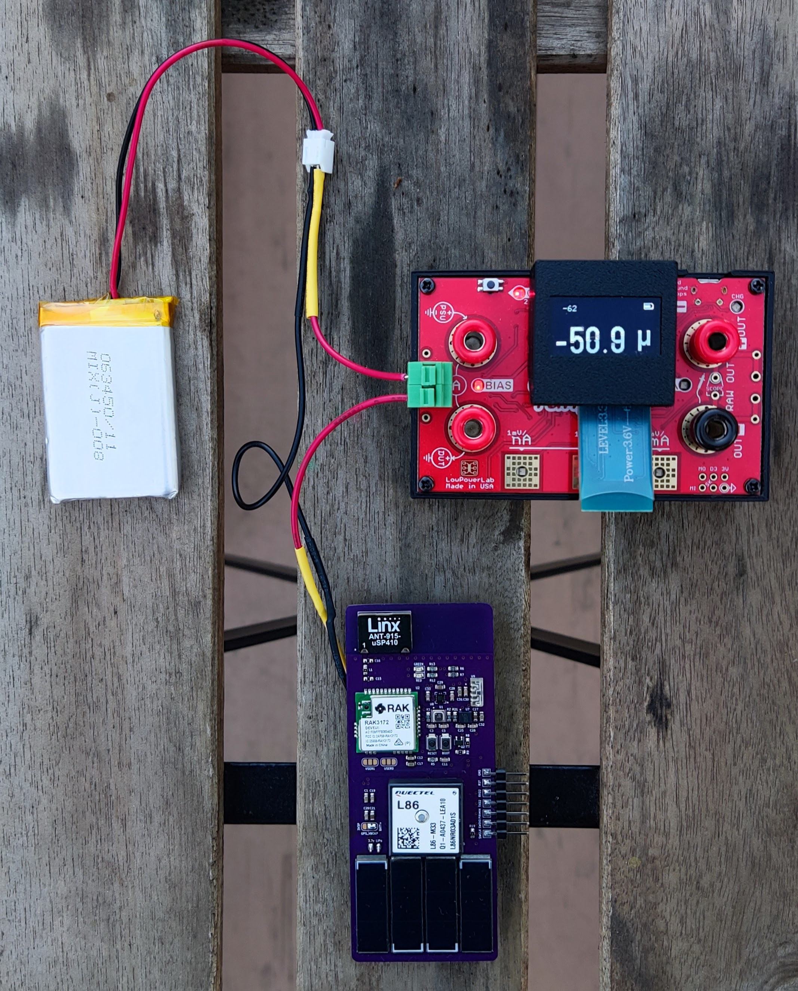
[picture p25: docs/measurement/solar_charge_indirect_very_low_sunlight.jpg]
solar_charge_indirect_very_low_sunlight


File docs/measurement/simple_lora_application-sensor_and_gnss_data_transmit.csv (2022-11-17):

Timestamp(ms) | Current(uA)
0 | 11.901
1 | 11.622
2 | 11.492
3 | 11.493
4 | 11.483
5 | 11.466
6 | 11.528
7 | 11.534
8 | 11.554
9 | 11.533
10 | 11.504
11 | 11.543
12 | 11.542
13 | 11.558
14 | 11.540
15 | 11.496
16 | 11.534
17 | 11.543
18 | 11.561
19 | 11.548
20 | 11.505
21 | 11.537
22 | 11.539
23 | 11.553
24 | 11.555
25 | 11.494
26 | 11.529
27 | 11.538
28 | 11.561
29 | 11.569
30 | 11.484
31 | 11.512
32 | 11.501
33 | 11.539
34 | 11.568
35 | 11.508
36 | 11.517
37 | 11.499
38 | 11.546
39 | 11.563
40 | 11.495
41 | 11.509
42 | 11.504
43 | 11.549
44 | 11.564
45 | 11.515
46 | 11.515
47 | 11.515
48 | 11.560
49 | 11.582
50 | 11.523
51 | 11.499
52 | 11.509
53 | 11.553
54 | 11.570
55 | 11.515
56 | 11.498
57 | 11.471
58 | 11.536
59 | 11.561
60 | 11.501
61 | 11.503
62 | 11.461
63 | 11.525
64 | 11.562
65 | 11.511
66 | 11.495
67 | 11.461
68 | 11.529
69 | 11.559
70 | 11.522
71 | 11.466
72 | 11.434
73 | 11.500
74 | 11.530
75 | 11.488
76 | 11.469
77 | 11.415
78 | 11.497
79 | 11.527
80 | 11.498
81 | 11.472
82 | 11.410
83 | 11.494
84 | 11.523
85 | 11.464
86 | 11.461
87 | 11.367
88 | 11.480
89 | 11.511
90 | 11.478
91 | 11.481
92 | 11.369
93 | 11.480
94 | 11.521
95 | 11.475
96 | 11.486
97 | 11.375
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

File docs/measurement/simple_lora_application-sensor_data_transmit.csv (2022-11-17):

Timestamp(ms) | Current(uA)
0 | 11.616
1 | 11.867
2 | 11.950
3 | 12.002
4 | 11.993
5 | 12.046
6 | 12.086
7 | 12.076
8 | 12.098
9 | 12.033
10 | 12.035
11 | 12.088
12 | 12.090
13 | 12.094
14 | 12.012
15 | 12.031
16 | 12.073
17 | 12.058
18 | 12.066
19 | 11.996
20 | 12.010
21 | 12.055
22 | 12.062
23 | 12.071
24 | 12.001
25 | 11.966
26 | 11.995
27 | 12.006
28 | 12.026
29 | 11.954
30 | 11.936
31 | 11.974
32 | 11.963
33 | 11.993
34 | 11.950
35 | 11.944
36 | 11.995
37 | 11.974
38 | 12.005
39 | 11.947
40 | 11.936
41 | 11.972
42 | 11.960
43 | 11.980
44 | 11.945
45 | 11.928
46 | 11.963
47 | 11.958
48 | 11.985
49 | 11.947
50 | 11.927
51 | 11.938
52 | 11.937
53 | 11.976
54 | 11.945
55 | 11.936
56 | 11.939
57 | 11.916
58 | 11.953
59 | 11.935
60 | 11.901
61 | 11.920
62 | 11.898
63 | 11.942
64 | 11.910
65 | 11.902
66 | 11.893
67 | 11.892
68 | 11.946
69 | 11.926
70 | 11.916
71 | 11.909
72 | 11.897
73 | 11.950
74 | 11.919
75 | 11.921
76 | 11.913
77 | 11.894
78 | 11.944
79 | 11.912
80 | 11.916
81 | 11.897
82 | 11.871
83 | 11.932
84 | 11.905
85 | 11.898
86 | 11.879
87 | 11.836
88 | 11.915
89 | 11.893
90 | 11.909
91 | 11.882
92 | 11.839
93 | 11.917
94 | 11.900
95 | 11.907
96 | 11.883
97 | 11.828
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

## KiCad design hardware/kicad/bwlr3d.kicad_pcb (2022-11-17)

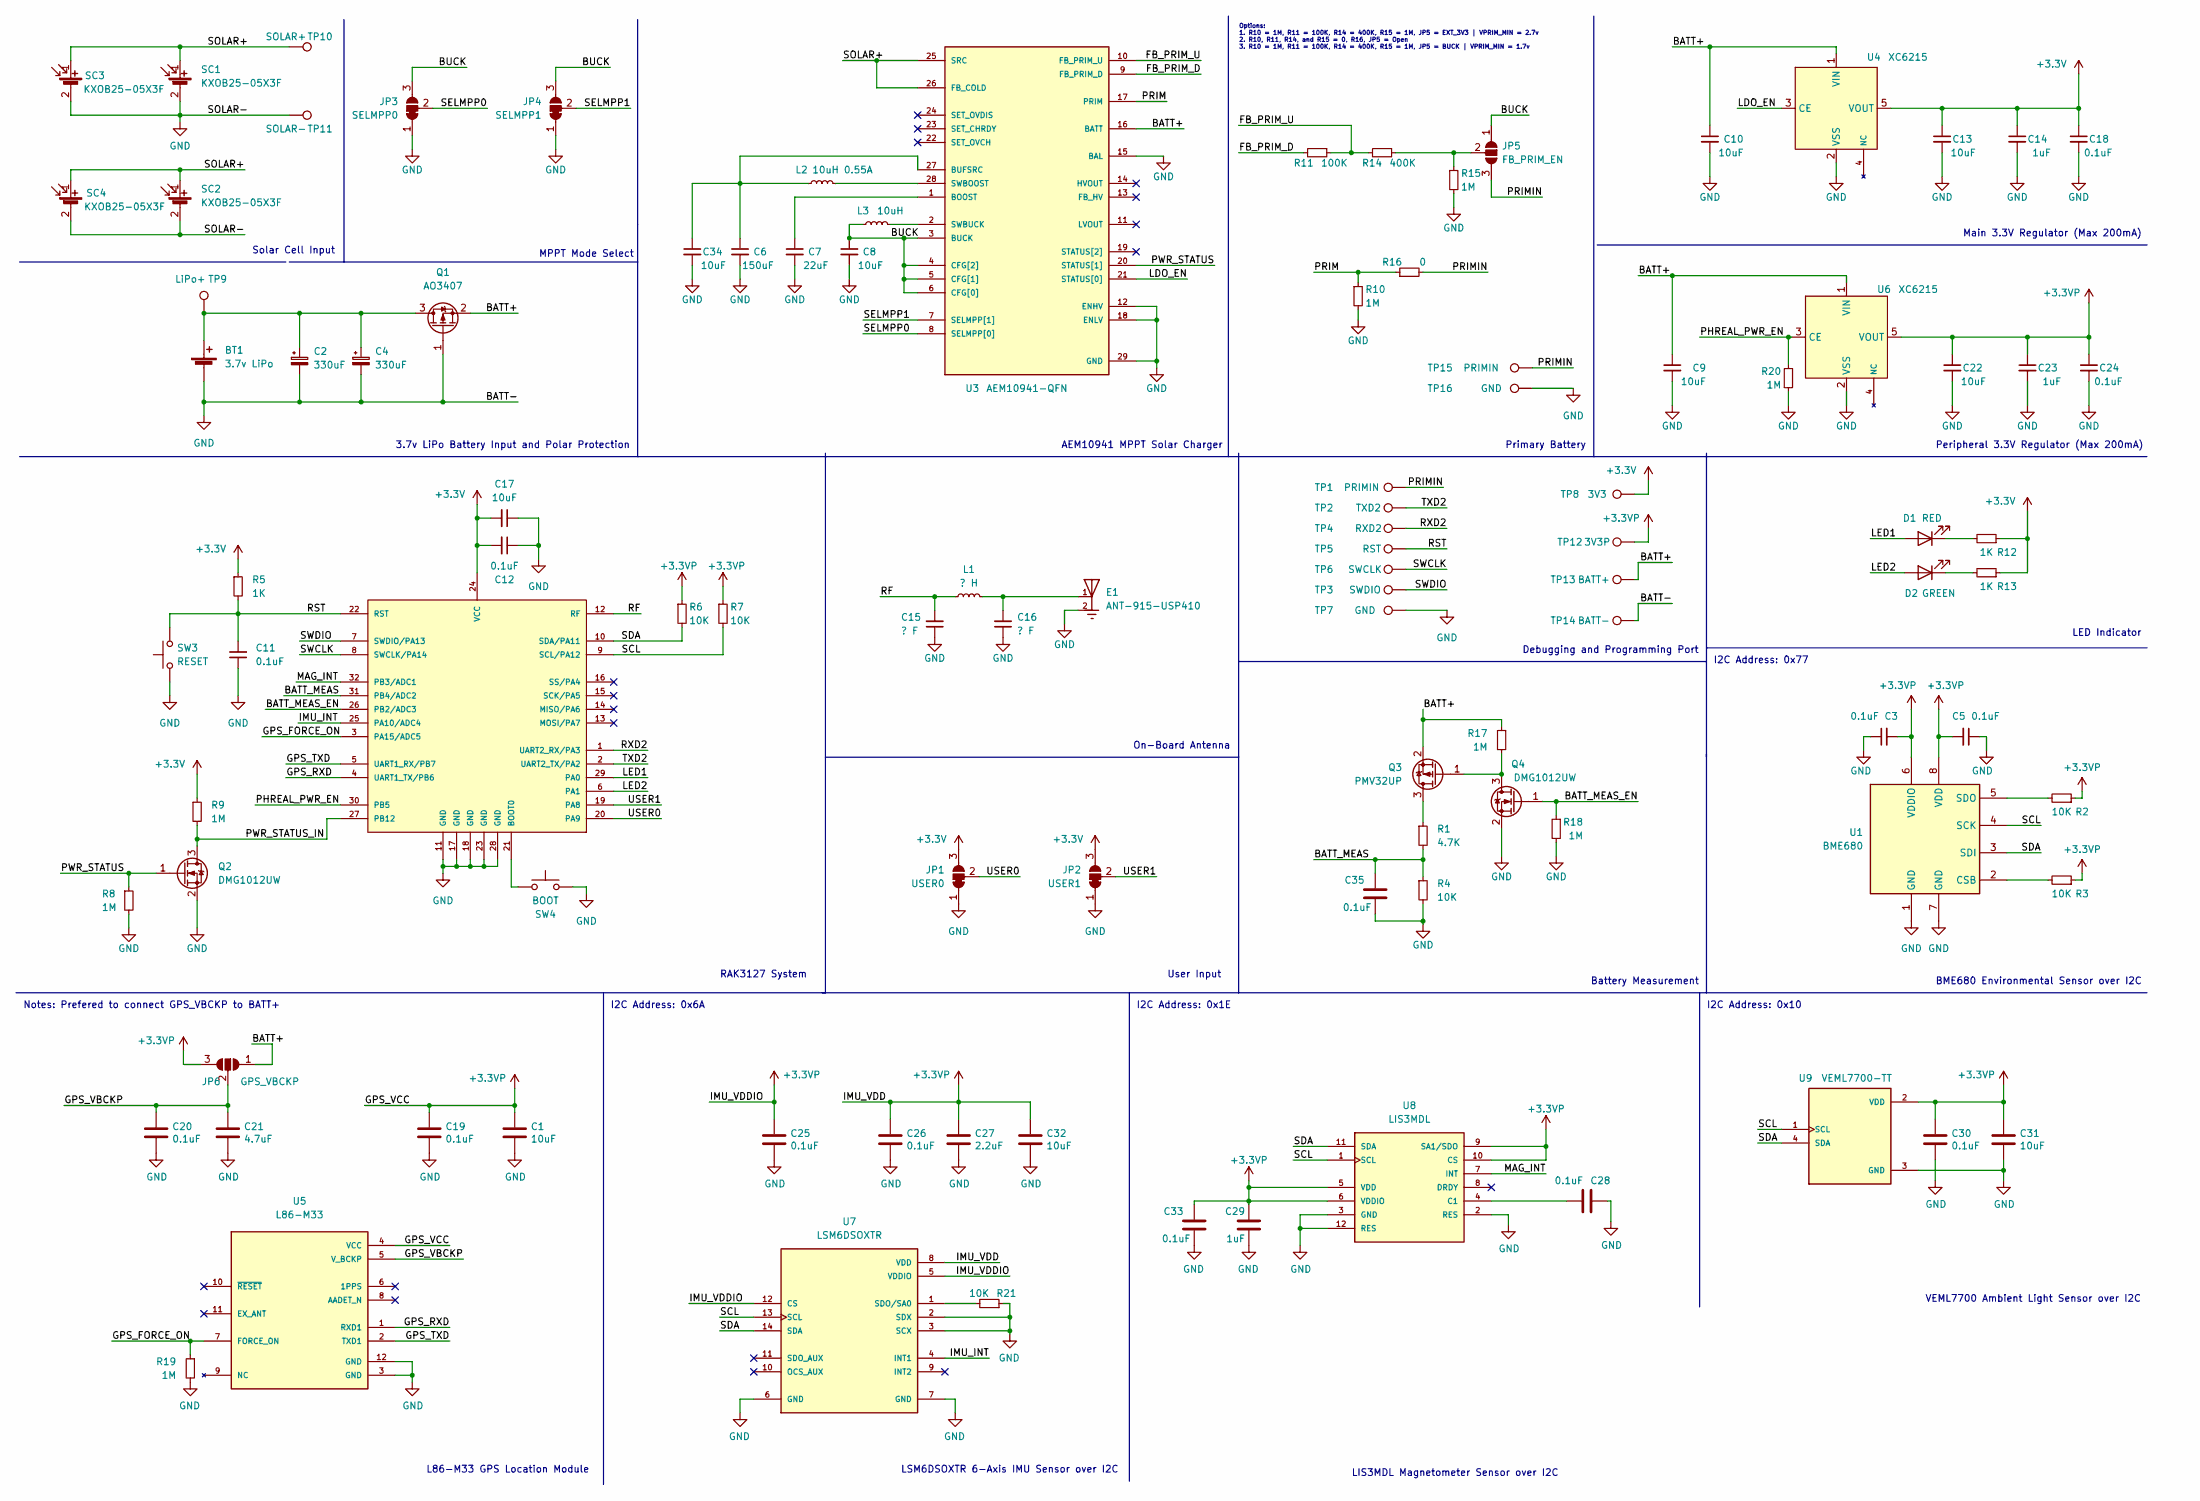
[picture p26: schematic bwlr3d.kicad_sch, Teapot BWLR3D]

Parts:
BT1: 3.7v LiPo; JST_PH_S2B-PH-K_1x02_P2.00mm_Horizontal
C1, C8, C9, C10, C13, C17, C22, C31, C32, C34: 10uF; C_0603_1608Metric
C2, C4: 330uF; CP_EIA-3528-15_AVX-H_Pad1.50x2.35mm_HandSolder
C3, C5, C11, C12, C18, C19, C20, C24, C25, C26, C28, C30, C33, C35: 0.1uF; C_0603_1608Metric
C6: 150uF; C_1210_3225Metric
C7: 22uF; C_0603_1608Metric
C14, C23, C29: 1uF; C_0603_1608Metric
C15, C16: ? F; C_0603_1608Metric
C21: 4.7uF; C_0603_1608Metric
C27: 2.2uF; C_0603_1608Metric
D1: RED; LED_0603_1608Metric
D2: GREEN; LED_0603_1608Metric
E1: ANT-915-USP410; XDCR_ANT-915-USP410; PARTREV N/A
JP1: USER0; SolderJumper-3_P1.3mm_Bridged12_RoundedPad1.0x1.5mm_NumberL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
JP2: USER1; SolderJumper-3_P1.3mm_Bridged12_RoundedPad1.0x1.5mm_NumberL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
JP3: SELMPP0; SolderJumper-3_P1.3mm_Bridged12_RoundedPad1.0x1.5mm_NumberL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
JP4: SELMPP1; SolderJumper-3_P1.3mm_Bridged12_RoundedPad1.0x1.5mm_NumberL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
JP5: FB_PRIM_EN; SolderJumper-3_P1.3mm_Open_RoundedPad1.0x1.5mm_NumberLabels
JP6: GPS_VBCKP; SolderJumper-3_P1.3mm_Open_RoundedPad1.0x1.5mm_NumberLabels
L1: ? H; L_0603_1608Metric
L2: 10uH 0.55A; IND_LPS4012-103MRB
L3: 10uH; L_0603_1608Metric
Q1: AO3407; SOT-23
Q2, Q4: DMG1012UW; SOT-323_SC-70
Q3: PMV32UP; SOT-23
R1: 4.7K; R_0603_1608Metric
R2, R3, R4, R6, R7, R21: 10K; R_0603_1608Metric
R5, R12, R13: 1K; R_0603_1608Metric
R8, R9, R10, R15, R17, R18, R19, R20: 1M; R_0603_1608Metric
R11: 100K; R_0603_1608Metric
R14: 400K; R_0603_1608Metric
R16: 0; R_0603_1608Metric
SC1, SC2, SC3, SC4: KXOB25-05X3F
SW3: RESET; SW_SPST_B3U-1000P
SW4: BOOT; SW_SPST_B3U-1000P
TP1: PRIMIN; TestPoint_Pad_1.5x1.5mm
TP2: TXD2; TestPoint_Pad_1.5x1.5mm
TP3: SWDIO; TestPoint_Pad_1.5x1.5mm
TP4: RXD2; TestPoint_Pad_1.5x1.5mm
TP5: RST; TestPoint_Pad_1.5x1.5mm
TP6: SWCLK; TestPoint_Pad_1.5x1.5mm
TP7: GND; TestPoint_Pad_1.5x1.5mm
TP8: 3V3; TestPoint_Pad_D1.0mm
TP9: LiPo+; TestPoint_Pad_D1.0mm
TP10: SOLAR+; TestPoint_Pad_D1.5mm
TP11: SOLAR-; TestPoint_Pad_D1.5mm
TP12: 3V3P; TestPoint_Pad_D1.0mm
TP13: BATT+; TestPoint_Pad_D1.0mm
TP14: BATT-; TestPoint_Pad_D1.0mm
TP15: PRIMIN; TestPoint_Pad_D2.0mm
TP16: GND; TestPoint_Pad_D2.0mm
U1: BME680; BME680-PSON80P300X300X100-8N
U2: RAK3172
U3: AEM10941-QFN; QFN-28-1EP_5x5mm_P0.5mm_EP3.35x3.35mm; PARTREV 1.4
U4, U6: XC6215; SOT-23-5_HandSoldering
U5: L86-M33; XCVR_L86-M33
U7: LSM6DSOXTR; PQFN50P250X300X97-14N_0.59x0.30
U8: LIS3MDL; LGA12_ST
U9: VEML7700-TT; XDCR_VEML7700-TT

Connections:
+3.3V: C12.2, C13.1, C14.1, C17.2, C18.1, JP1.3 (B), JP2.3 (B), R5.1, R9.1, R12.1, R13.1, TP8.1, U2.24 (VCC), U4.5 (VOUT)
+3.3VP: C1.1, C3.2, C5.2, C19.1, C22.1, C23.1, C24.1, C25.1, C26.1, C27.1, C29.1, C30.1, C31.1, C32.1, C33.2, JP6.3 (B), R2.1, R3.1, R6.1, R7.1, TP12.1, U1.6 (VDDIO), U1.8 (VDD), U5.4 (VCC), U6.5 (VOUT), U7.5 (VDDIO), U7.8 (VDD), U7.12 (CS), U8.5 (VDD), U8.6 (VDDIO), U8.9 (SA1/SDO), U8.10 (CS), U9.2 (VDD)
/BATT+: C9.1, C10.1, JP6.1 (A), Q1.2 (S), Q3.2 (S), R17.1, TP13.1, U3.16 (BATT), U4.1 (VIN), U6.1 (VIN)
/BATT_MEAS: C35.2, R1.2, R4.1, U2.31 (PB4/ADC2)
/BATT_MEAS_EN: Q4.1 (G), R18.1, U2.26 (PB2/ADC3)
/BUCK: C8.1, JP3.3 (B), JP4.3 (B), JP5.1 (A), L3.1, U3.3 (BUCK), U3.4 (CFG[2]), U3.5 (CFG[1]), U3.6 (CFG[0])
/FB_PRIM_D: R11.2, U3.9 (FB_PRIM_D)
/FB_PRIM_U: R11.1, R14.2, U3.10 (FB_PRIM_U)
/GPS_FORCE_ON: R19.1, U2.3 (PA15/ADC5), U5.7 (FORCE_ON)
/GPS_RXD: U2.4 (UART1_TX/PB6), U5.1 (RXD1)
/GPS_TXD: U2.5 (UART1_RX/PB7), U5.2 (TXD1)
/GPS_VBCKP: C20.1, C21.1, JP6.2 (C), U5.5 (V_BCKP)
/IMU_INT: U2.25 (PA10/ADC4), U7.4 (INT1)
/LDO_EN: U3.21 (STATUS[0]), U4.3 (CE)
/LED1: D1.2 (A), U2.29 (PA0)
/LED2: D2.2 (A), U2.6 (PA1)
/MAG_INT: U2.32 (PB3/ADC1), U8.7 (INT)
/PHREAL_PWR_EN: R20.1, U2.30 (PB5), U6.3 (CE)
/PRIM: R10.1, R16.1, U3.17 (PRIM)
/PRIMIN: JP5.3 (B), R16.2, TP1.1, TP15.1
/PWR_STATUS: Q2.1 (G), R8.1, U3.20 (STATUS[1])
/PWR_STATUS_IN: Q2.3 (D), R9.2, U2.27 (PB12)
/RF: C15.2, L1.1, U2.12 (RF)
/RST: C11.2, R5.2, SW3.2, TP5.1, U2.22 (RST)
/RXD2: TP4.1, U2.1 (UART2_RX/PA3)
/SCL: R7.2, U1.4 (SCK), U2.9 (SCL/PA12), U7.13 (SCL), U8.1 (SCL), U9.1 (SCL)
/SDA: R6.2, U1.3 (SDI), U2.10 (SDA/PA11), U7.14 (SDA), U8.11 (SDA), U9.4 (SDA)
/SELMPP0: JP3.2 (C), U3.8 (SELMPP[0])
/SELMPP1: JP4.2 (C), U3.7 (SELMPP[1])
/SOLAR+: SC1.1 (+), SC2.1 (+), SC3.1 (+), SC4.1 (+), TP10.1, U3.25 (SRC), U3.26 (FB_COLD)
/SWCLK: TP6.1, U2.8 (SWCLK/PA14)
/SWDIO: TP3.1, U2.7 (SWDIO/PA13)
/TXD2: TP2.1, U2.2 (UART2_TX/PA2)
/USER0: JP1.2 (C), U2.20 (PA9)
/USER1: JP2.2 (C), U2.19 (PA8)
GND: BT1.2 (-), C1.2, C2.2, C3.1, C4.2, C5.1, C6.2, C7.2, C8.2, C9.2, C10.2, C11.1, C12.1, C13.2, C14.2, C15.1, C16.1, C17.1, C18.2, C19.2, C20.2, C21.2, C22.2, C23.2, C24.2, C25.2, C26.2, C27.2, C28.2, C29.2, C30.2, C31.2, C32.2, C33.1, C34.2, C35.1, E1.2, JP1.1 (A), JP2.1 (A), JP3.1 (A), JP4.1 (A), Q1.1 (G), Q2.2 (S), Q4.2 (S), R4.2, R8.2, R10.2, R15.2, R18.2, R19.2, R20.2, R21.1, SC1.2 (-), SC2.2 (-), SC3.2 (-), SC4.2 (-), SW3.1, SW4.2, TP7.1, TP11.1, TP14.1, TP16.1, U1.1 (GND), U1.7 (GND), U2.11 (GND), U2.17 (GND), U2.18 (GND), U2.23 (GND), U2.28 (GND), U3.12 (ENHV), U3.15 (BAL), U3.18 (ENLV), U3.29 (GND), U4.2 (VSS), U5.3 (GND), U5.12 (GND), U6.2 (VSS), U7.2 (SDX), U7.3 (SCX), U7.6 (GND), U7.7 (GND), U8.2 (RES), U8.3 (GND), U8.12 (RES), U9.3 (GND)
unnamed: BT1.1 (+), C2.1, C4.1, Q1.3 (D), TP9.1
unnamed: C7.1, U3.1 (BOOST)
unnamed: C16.2, E1.1, L1.2
unnamed: C28.1, U8.4 (C1)
unnamed: C6.1, C34.1, L2.1, U3.27 (BUFSRC)
unnamed: D1.1 (K), R12.2
unnamed: D2.1 (K), R13.2
unnamed: JP5.2 (C), R14.1, R15.1
unnamed: L2.2, U3.28 (SWBOOST)
unnamed: L3.2, U3.2 (SWBUCK)
unnamed: Q3.1 (G), Q4.3 (D), R17.2
unnamed: Q3.3 (D), R1.1
unnamed: R2.2, U1.5 (SDO)
unnamed: R3.2, U1.2 (CSB)
unnamed: R21.2, U7.1 (SDO/SA0)
unnamed: SW4.1, U2.21 (BOOT0)

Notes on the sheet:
On-Board Antenna
RAK3127 System
I2C Address: 0x1E
MPPT Mode Select
BME680 Environmental Sensor over I2C
LED Indicator
LSM6DSOXTR 6-Axis IMU Sensor over I2C
AEM10941 MPPT Solar Charger
Notes: Prefered to connect GPS_VBCKP to BATT+
Battery Measurement
LIS3MDL Magnetometer Sensor over I2C
VEML7700 Ambient Light Sensor over I2C
I2C Address: 0x6A
Solar Cell Input
L86-M33 GPS Location Module
I2C Address: 0x10
Primary Battery
3.7v LiPo Battery Input and Polar Protection
User Input
I2C Address: 0x77
Peripheral 3.3V Regulator (Max 200mA)
Main 3.3V Regulator (Max 200mA)
Options: 1. R10 = 1M, R11 = 100K, R14 = 400K, R15 = 1M, JP5 = EXT_3V3 | VPRIM_MIN = 2.7v 2. R10, R11, R14, and R15 = 0, R16, JP5 = Open 3. R10 = 1M, R11 = 100K, R14 = 400K, R15 = 1M, JP5 = BUCK | VPRIM_MIN = 1.7v
Debugging and Programming Port

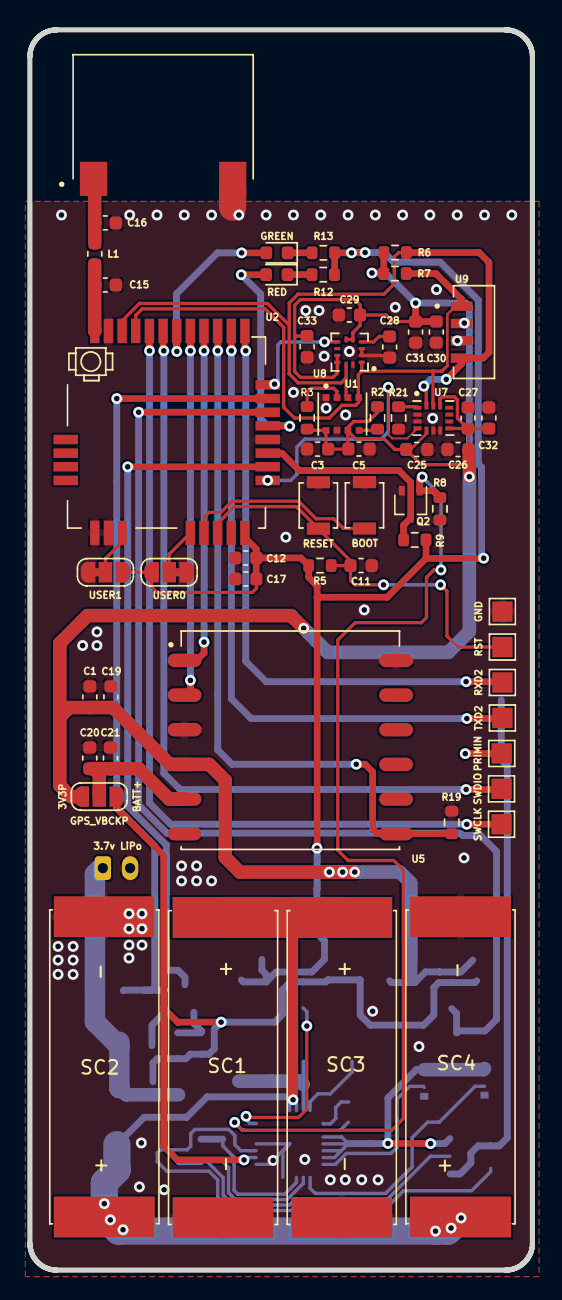
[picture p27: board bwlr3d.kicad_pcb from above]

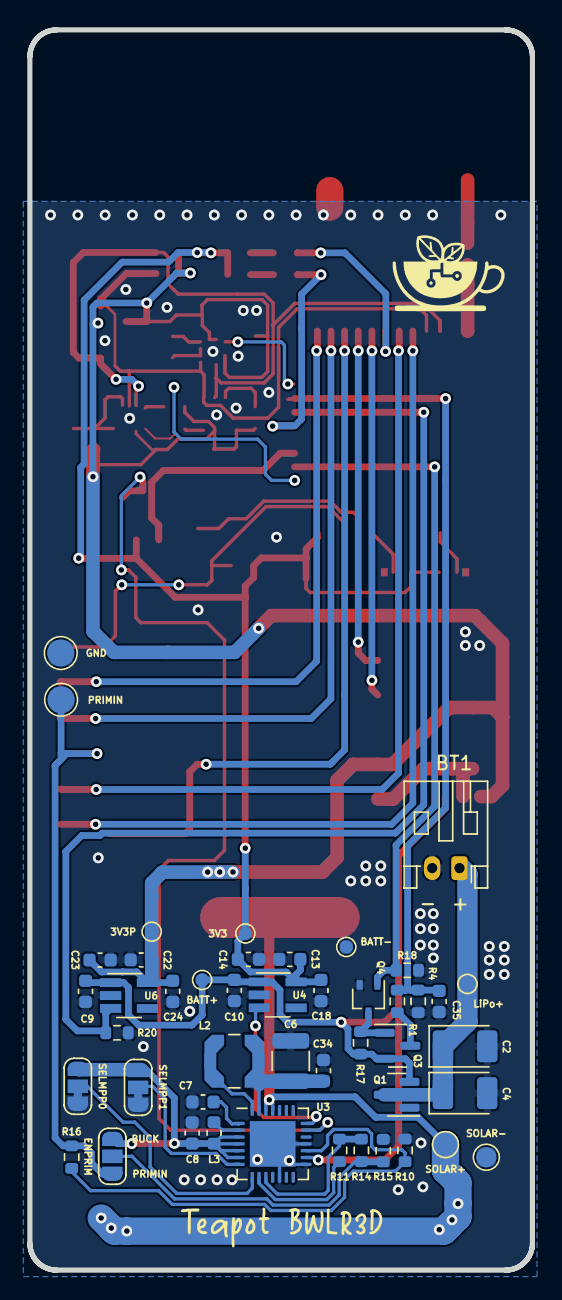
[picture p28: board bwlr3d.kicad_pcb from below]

Board: 2 copper layers, 36.8 x 90.9 mm, 104 parts (46 on the bottom side), 52 nets.

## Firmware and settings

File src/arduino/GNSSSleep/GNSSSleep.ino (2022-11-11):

#include <TinyGPSPlus.h>

/* Teapot BWLR3D Base System Control */
/* adc to battery multiplier */
#define ADC_TO_BATTERY  0.00120919472

/* board revision */
#define BOARD_REVISION  0x02 // set this based on the board you have

/* pin definition */
#define RED_LED               PA0
#define GREEN_LED             PA1
#define PERIPHERAL_POWER_EN   PB5
#define BATT_MEASURE_EN       PB2
#define POWER_STATUS          PB12
#define GPS_FORCE_ON          PA15
#define GPS_TXD               PB7
#define GPS_RXD               PB6
#define I2C_SDA               PA11
#define I2C_SCL               PA12
#define MAG_INT               PB3
#if BOARD_REVISION == 0x01
  #define IMU_INT             PB4
  #define BATT_MEASURE        PA10
#elif BOARD_REVISION == 0x02
  #define IMU_INT             PA10
  #define BATT_MEASURE        PB4
#else
  #ifndef BOARD_REVISION
    #error "BOARD_REVISION not set"
  #endif
  #error "invalid BOARD_REVISION value"
#endif

void EnablePeripheral(bool power)
{
  if( power ){
    
    // enable GPS serial
    Serial1.begin(9600);
    
    // enable sensor I2C bus
    Wire.begin();
    
    // power-on 3.3v rail to all peripheral
    pinMode(PERIPHERAL_POWER_EN, OUTPUT);
    digitalWrite(PERIPHERAL_POWER_EN, HIGH);
  } else {
    
    // disable GPS serial
    Serial1.end();
    pinMode(GPS_TXD, INPUT);
    pinMode(GPS_RXD, INPUT);
  
    // disable I2C
    Wire.end();
    pinMode(I2C_SDA, INPUT);
    pinMode(I2C_SCL, INPUT);

    
    // power-off 3.3v rail to all peripheral
    pinMode(PERIPHERAL_POWER_EN, OUTPUT);
    digitalWrite(PERIPHERAL_POWER_EN, LOW); 
  }
}

void EnableGnss( bool enable )
{  
  if( enable )
  {
    // wake gps, incase it's off
    pinMode(GPS_FORCE_ON, OUTPUT);
    digitalWrite(GPS_FORCE_ON, HIGH);
  }
  else 
  {
    // open pin to allow GPS to go to sleep (backup mode)
    pinMode(GPS_FORCE_ON, INPUT);
    
    // prepare command
    unsigned char backup_mode_command[15];
    String base_backup_mode_command = ("$PMTK225,4*2F"); 
    const char tr[] = {0xD, 0xA};
    base_backup_mode_command.getBytes(backup_mode_command, sizeof(backup_mode_command));
    memcpy(backup_mode_command+13, tr, 2); 

    // send sleep command to gps
    Serial1.write(backup_mode_command, sizeof(backup_mode_command));

    // clear incoming uart data
    Serial1.flush();
    while (Serial1.available()) Serial1.read();
  }
}

void Initialize(){    
  // disable unnecessary pin
  pinMode(MAG_INT, INPUT);
  pinMode(IMU_INT, INPUT);
  pinMode(POWER_STATUS, INPUT);
  
  // setup battery read measure
  analogReadResolution(14);
  pinMode(BATT_MEASURE, INPUT);
  pinMode(BATT_MEASURE_EN, OUTPUT);
  digitalWrite(BATT_MEASURE_EN, LOW);
  
  // setup led pin
  pinMode(GREEN_LED, OUTPUT);
  digitalWrite(GREEN_LED, HIGH);
  pinMode(RED_LED, OUTPUT);
  digitalWrite(RED_LED, HIGH);

  // initialize and sleep GNSS
  EnablePeripheral(true);
  delay( 1000 );
  EnableGnss( false );
  delay( 1000 );
  
  // power-off all peripheral
  EnablePeripheral(false);
  delay( 1000 );
}

int ReadBatteryAdc()
{
  // TODO: investigate. it seems pin always disabled at every loop.
  //       always set to output at every ADC read.
  pinMode(BATT_MEASURE_EN, OUTPUT);
  digitalWrite(BATT_MEASURE_EN, HIGH);
  const int battery_adc = analogRead( BATT_MEASURE );
  digitalWrite(BATT_MEASURE_EN, LOW);
  return battery_adc;
}

float ReadBatteryVoltage()
{
  return ((float) ReadBatteryAdc()) * ADC_TO_BATTERY;
}

bool ReadPowerStatus()
{
  // TODO: investigate. it seems pin always disabled at every loop.
  //       always set to input at every digital read.
  pinMode(POWER_STATUS, INPUT);
  return digitalRead(POWER_STATUS);
}
/* Teapot BWLR3D Base System Control */


TinyGPSPlus gps;
void setup()
{
  
  api.system.restoreDefault();
  Serial.begin(115200);

  // initialize pins
  Initialize();
  
  // power-on all peripheral
  EnablePeripheral( true );
  EnableGnss( true );
  
  Serial.println();
  Serial.println(F("Sats HDOP  Latitude   Longitude   Fix  Date       Time     Date Alt    Chars Sentences Checksum"));
  Serial.println(F("           (deg)      (deg)       Age                      Age  (m)    RX    RX        Fail"));
  Serial.println(F("------------------------------------------------------------------------------------------------"));
}


uint32_t start_time;
//uint32_t stop_at_time = 600000; // disable GPS every 10 minute
uint32_t stop_at_time = 60000; // disable GPS every 1 minute
uint32_t sleep_time = 5000; // sleep for 5 seconds
void loop()
{
  /* print incoming GPS data */
  printInt(gps.satellites.value(), gps.satellites.isValid(), 5);
  printFloat(gps.hdop.hdop(), gps.hdop.isValid(), 6, 1);
  printFloat(gps.location.lat(), gps.location.isValid(), 11, 6);
  printFloat(gps.location.lng(), gps.location.isValid(), 12, 6);
  printInt(gps.location.age(), gps.location.isValid(), 5);
  printDateTime(gps.date, gps.time);
  printFloat(gps.altitude.meters(), gps.altitude.isValid(), 7, 2);
  printInt(gps.charsProcessed(), true, 6);
  printInt(gps.sentencesWithFix(), true, 10);
  printInt(gps.failedChecksum(), true, 9);
  Serial.println();
  
  smartDelay(1000);

  if (millis() > 5000 && gps.charsProcessed() < 10)
    Serial.println(F("No GPS data received: check wiring"));


  /* set gps to sleep every stop_at_time ms */
  if( start_time == 0 ){
    start_time = millis();
  }
  if( millis() - start_time > stop_at_time ){

    // disable gps
    EnableGnss( false );
    delay( 1000 );
    // power-off all peripheral
    EnablePeripheral(  false );

    // set device to sleep
    Serial.println("Set device to sleep");
    api.system.sleep.all(sleep_time);

    // wake gps
    EnableGnss( true );
    
    // power-on all peripheral
    EnablePeripheral(  true );

    // reset timer
    start_time = millis();
  }
}

// This custom version of delay() ensures that the gps object
// is being "fed".
static void smartDelay(unsigned long ms)
{
  unsigned long start = millis();
  do 
  {
    while (Serial1.available())
      gps.encode(Serial1.read());
  } while (millis() - start < ms);
}

static void printFloat(float val, bool valid, int len, int prec)
{
  if (!valid)
  {
    while (len-- > 1)
      Serial.print('*');
    Serial.print(' ');
  }
  else
  {
    Serial.print(val, prec);
    int vi = abs((int)val);
    int flen = prec + (val < 0.0 ? 2 : 1); // . and -
    flen += vi >= 1000 ? 4 : vi >= 100 ? 3 : vi >= 10 ? 2 : 1;
    for (int i=flen; i<len; ++i)
      Serial.print(' ');
  }
  smartDelay(0);
}

static void printInt(unsigned long val, bool valid, int len)
{
  char sz[32] = "*****************";
  if (valid)
    sprintf(sz, "%ld", val);
  sz[len] = 0;
  for (int i=strlen(sz); i<len; ++i)
    sz[i] = ' ';
  if (len > 0) 
    sz[len-1] = ' ';
  Serial.print(sz);
  smartDelay(0);
}

static void printDateTime(TinyGPSDate &d, TinyGPSTime &t)
{
  if (!d.isValid())
  {
    Serial.print(F("********** "));
  }
  else
  {
    char sz[32];
    sprintf(sz, "%02d/%02d/%02d ", d.month(), d.day(), d.year());
    Serial.print(sz);
  }
  
  if (!t.isValid())
  {
    Serial.print(F("******** "));
  }
  else
  {
    char sz[32];
    sprintf(sz, "%02d:%02d:%02d ", t.hour(), t.minute(), t.second());
    Serial.print(sz);
  }

  printInt(d.age(), d.isValid(), 5);
  smartDelay(0);
}

static void printStr(const char *str, int len)
{
  int slen = strlen(str);
  for (int i=0; i<len; ++i)
    Serial.print(i<slen ? str[i] : ' ');
  smartDelay(0);
}

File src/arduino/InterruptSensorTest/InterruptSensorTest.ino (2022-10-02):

#include "Adafruit_LIS3MDL.h"
#include "SparkFunLSM6DSO.h"
#include "Adafruit_LSM6DSOX.h"
#include "Adafruit_BME680.h"
#include "Adafruit_VEML7700.h"

#define SEALEVELPRESSURE_HPA (1013.25)

uint16_t errorsAndWarnings = 0;

// Teapot BWLR3D pins
#define LED0                PA0
#define LED1                PA1
#define PERIPHERAL_POWER_EN PB5
#define BATT_MEASURE_EN     PB2
#define POWER_STATUS        PB12
#define GPS_FORCE_ON        PA15
#define GPS_TXD             PB7
#define GPS_RXD             PB6
#define I2C_SDA             PA11
#define I2C_SCL             PA12
#define MAG_INT             PB3
#define IMU_INT             PB4   // new rev is PA10
#define BATT_MEASURE        PA10  // new rev is PB4


LSM6DSO myIMU;
Adafruit_LSM6DSOX sox;
Adafruit_LIS3MDL lis3mdl;
Adafruit_BME680 bme; // I2C
Adafruit_VEML7700 veml;
void setup(void) {
  /* initialize system pin */
  initializeSystem();
  /* initialize sensor */
  enableSensorCommunication();
  /* configure sensor settings */
  configureSensor();
  
  /* configure GPS */
  Serial.println("================ Setup GPS ================");
  delay(2000);
  pinMode(GPS_FORCE_ON, INPUT); // open pin to allow GPS to go to sleep (backup mode)
  // set gps to sleep
  setGPSToBackupMode();
  
}

void loop() {  
  /* disable sensor comm and then sleep */
//  disableSensorCommunication();
//  api.system.sleep.all(10000);
//
//  Serial.println();
//  Serial.println("================ Sensor Wakes Up ================");
//  enableSensorCommunication();
  /* read sensor data */
//  readSensorData();
//  if( digitalRead(IMU_INT) == HIGH )
//  {
//    Serial.print("\nAccelerometer:\n");
//    Serial.print(" X = ");
//    Serial.println(myIMU.readFloatAccelX(), 3);
//    Serial.print(" Y = ");
//    Serial.println(myIMU.readFloatAccelY(), 3);
//    Serial.print(" Z = ");
//    Serial.println(myIMU.readFloatAccelZ(), 3);
//  }
//
//  if( digitalRead(IMU_INT) == HIGH )
//  {
//    Serial.print("\nGyroscope:\n");
//    Serial.print(" X = ");
//    Serial.println(myIMU.readFloatGyroX(), 3);
//    Serial.print(" Y = ");
//    Serial.println(myIMU.readFloatGyroY(), 3);
//    Serial.print(" Z = ");
//    Serial.println(myIMU.readFloatGyroZ(), 3);
//  }


    Serial.print("IMU Interrupt: ");
    Serial.println(digitalRead(IMU_INT));
    delay(100);

}

void initializeSystem(){  
  api.system.restoreDefault();
  Serial.begin(115200);
  
  // power-on all peripheral
  pinMode(PERIPHERAL_POWER_EN, OUTPUT);
  digitalWrite(PERIPHERAL_POWER_EN, HIGH);

  // disable unnecessary pin
  pinMode(MAG_INT, INPUT);
  pinMode(IMU_INT, INPUT);
  pinMode(POWER_STATUS, INPUT);
  pinMode(BATT_MEASURE, INPUT);
  pinMode(BATT_MEASURE_EN, INPUT);
  pinMode(LED0, INPUT);
  pinMode(LED1, INPUT);

  pinMode(GPS_FORCE_ON, INPUT); // open pin to allow GPS to go to sleep (backup mode)
}

void enableSensorCommunication() {
  // enable GPS serial
  Serial1.begin(9600);
  
  // enable sensor I2C bus
  Wire.begin();
}

void disableSensorCommunication() {
  // disable GPS serial
  Serial1.end();
  pinMode(GPS_TXD, INPUT);
  pinMode(GPS_RXD, INPUT);

  // disable I2C
  Wire.end();
  pinMode(I2C_SDA, INPUT);
  pinMode(I2C_SCL, INPUT);
}

void readSensorData(){
  /* Get a new normalized sensor event */
  sensors_event_t accel;
  sensors_event_t gyro;
  sensors_event_t temp;
  sensors_event_t mag; 


  /* Read lux sensor */
  Serial.println("================ VEML7700 Sensor ================");
  Serial.print("raw ALS: "); Serial.println(veml.readALS());
  Serial.print("raw white: "); Serial.println(veml.readWhite());
  Serial.print("lux: "); Serial.println(veml.readLux());

  /* Read Mag sensor */
  Serial.println("================ LIS3MDL Sensor ================");
  lis3mdl.getEvent(&mag);
  /* Display the results (magnetic field is measured in uTesla) */
  Serial.print("X: "); Serial.print(mag.magnetic.x);
  Serial.print(" \tY: "); Serial.print(mag.magnetic.y); 
  Serial.print(" \tZ: "); Serial.print(mag.magnetic.z); 
  Serial.println(" uTesla ");

  /* Read IMU sensor */
  Serial.println("================ LSM6DS0X Sensor ================");
  sox.getEvent(&accel, &gyro, &temp);
  Serial.print("Temperature ");
  Serial.print(temp.temperature);
  Serial.println(" deg C");

  /* Display the results (acceleration is measured in m/s^2) */
  Serial.print("Accel X: ");
  Serial.print(accel.acceleration.x);
  Serial.print(" \tY: ");
  Serial.print(accel.acceleration.y);
  Serial.print(" \tZ: ");
  Serial.print(accel.acceleration.z);
  Serial.println(" m/s^2 ");

  /* Display the results (rotation is measured in rad/s) */
  Serial.print("Gyro X: ");
  Serial.print(gyro.gyro.x);
  Serial.print(" \tY: ");
  Serial.print(gyro.gyro.y);
  Serial.print(" \tZ: ");
  Serial.print(gyro.gyro.z);
  Serial.println(" radians/s ");

  Serial.println("================ BME68x Sensor ================");
  if (! bme.performReading()) {
    Serial.println("Failed to perform reading :(");
    return;
  }
  Serial.print("Temperature = ");
  Serial.print(bme.temperature);
  Serial.println(" *C");

  Serial.print("Pressure = ");
  Serial.print(bme.pressure / 100.0);
  Serial.println(" hPa");

  Serial.print("Humidity = ");
  Serial.print(bme.humidity);
  Serial.println(" %");

  Serial.print("Gas = ");
  Serial.print(bme.gas_resistance / 1000.0);
  Serial.println(" KOhms");

  Serial.print("Approx. Altitude = ");
  Serial.print(bme.readAltitude(SEALEVELPRESSURE_HPA));
  Serial.println(" m");
}
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

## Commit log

2022-08-25 add teapot kicad library
2022-09-03 update library and footprint
    [bwlr3d.kicad_pcb, bwlr3d.kicad_sch]
2022-09-25 switch IMU_INT with BATT_MEAS, switch I2C pull-up to 3V3P, and add GND stitch
    [bwlr3d.kicad_pcb, bwlr3d.kicad_sch]
2022-10-09 update IMUTest
2022-11-09 change voltage divider value to 4.7K and 10K, add 0.1uF capacitor to voltage divider
    [bwlr3d.kicad_pcb, bwlr3d.kicad_sch]
2022-11-09 release board revision 1
    [bwlr3d.kicad_pcb, bwlr3d.kicad_sch]
2022-11-09 add remaining hardware files
    [bill_of_materials.csv, bottom.stl, bottom_with_programming_port.stl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]
2022-11-14 power-off gnss module when not needed
2022-11-17 add measurement docs
    [gnss_fix_cold_start.csv, gnss_fix_hot.csv, sensor_read_and_gnss_fix_hot_start.csv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]
2022-11-17 change revision number
    [bwlr3d.kicad_pcb, bwlr3d.kicad_sch]
2022-11-17 add src/arduino readme
2022-11-18 add 3d assembedled board
    [assembeld_board.stl]
2022-11-19 update src/arduino readme
2024-08-06 update bill of materials and name file
    [TeapotlabsBWLR3D-RAK11720-IPEX_BOM.csv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]

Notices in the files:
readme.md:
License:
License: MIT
